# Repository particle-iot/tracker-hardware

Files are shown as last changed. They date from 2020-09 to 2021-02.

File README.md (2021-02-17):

# Tracker Hardware Resources

*Hardware repository for the Tracker SoM evaluation board and carrier board (Tracker One)*

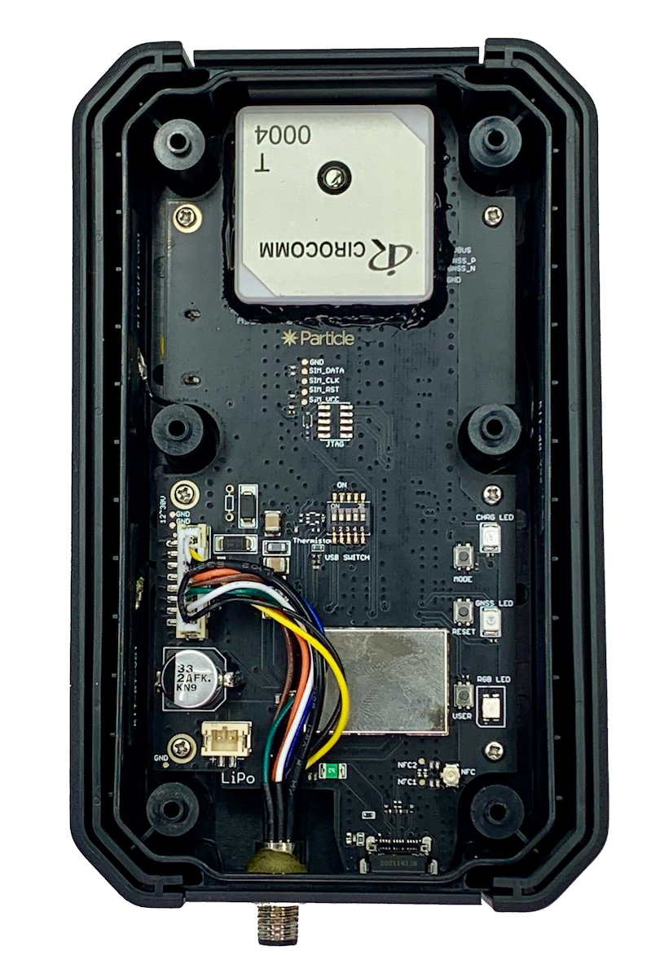
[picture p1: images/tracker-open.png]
Tracker One


Datasheets:

- [Tracker SoM](https://docs.particle.io/datasheets/asset-tracking/tracker-som-datasheet/)
- [Tracker SoM Evaluation Board](https://docs.particle.io/datasheets/asset-tracking/tracker-som-eval-board/)
- [Tracker One](https://docs.particle.io/datasheets/asset-tracking/tracker-one/)

In this repository you can find the following directories:

- eagle-eval: The Tracker SoM evaluation board
- eagle-carrier: The Tracker carrier board (the board in the Tracker One)

Within the Eagle directories are the standard Eagle files:

- *.sch Schematic file
- *.sch.pdf PDF version of the schematic (handy if you don't have Eagle CAD)
- *.brd Board Layout file
- *.lbr Library containing all of the components in the sch/brd files
- *.rar or *.zip Gerber files
- *.cam CAM file used to produce the Gerber file

The boards are identical for both Tracker SoM versions (T402 and T523).

Other useful resources include:

- [Creating your first Tracker SoM board tutorial](https://docs.particle.io/tutorials/asset-tracking/tracker-som-first-board/).

## Version History

### Tracker One (Carrier Board) v1.1 (2020-08-18)

1. Added TS3A5018 analog switch for isolate M8 IO pins.
2. Recalculated impedance, modified RF 50 ohm and USB 90 ohm trace width.
3. Added CAN BUS 5V output bypass fuse F2.

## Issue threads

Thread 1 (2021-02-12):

Potentially Incorrect Part Number

dan-os, 2021-02-12:
Hi there,

I noticed that LED3 (the RGB Particle status LED) from the "eagle-carrier" schematic has the part reference "LTST-T680UGWT" - I believe this is incorrect since this refers to a 2-pin green LED. I believe the intended part is the "150141M173100" by WURTH ELEKTRONIK.

Thanks for all your work!

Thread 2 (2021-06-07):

Schematics is not searchable

jhnlmn, 2021-06-07:
AT SoM Carrier Board V1.1 schematic.pdf
contains only screen shots from the schematics, which are neither searchable nor copyable.
All other chip/module makers provide schematics in PDF, where I can:
- search for a part name, for a trace name, etc
- copy part name to a browser to search for datasheet
but your schematics us close to be useless. I tried to use OCR on it, but it generates too many errors.
Please, provide real schematics for the Tracker

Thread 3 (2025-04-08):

Getting the Firmware Off of a Tracker One

redchairlabs, 2025-04-08:
I have been asked by a client to troubleshoot a Tracker One that is installed on a piece of equipment they own. The TO is receiving information via a CAN bus conenction but only a fraction of the data appears to be relayed out via the TO. Is there any way that I can pull the firmware off of the TO and verify that the CAN bus data file is configured correctly?

I have not worked with the Particle devices before and I am a bit unsure of how to configure the CAN bus connection in them.

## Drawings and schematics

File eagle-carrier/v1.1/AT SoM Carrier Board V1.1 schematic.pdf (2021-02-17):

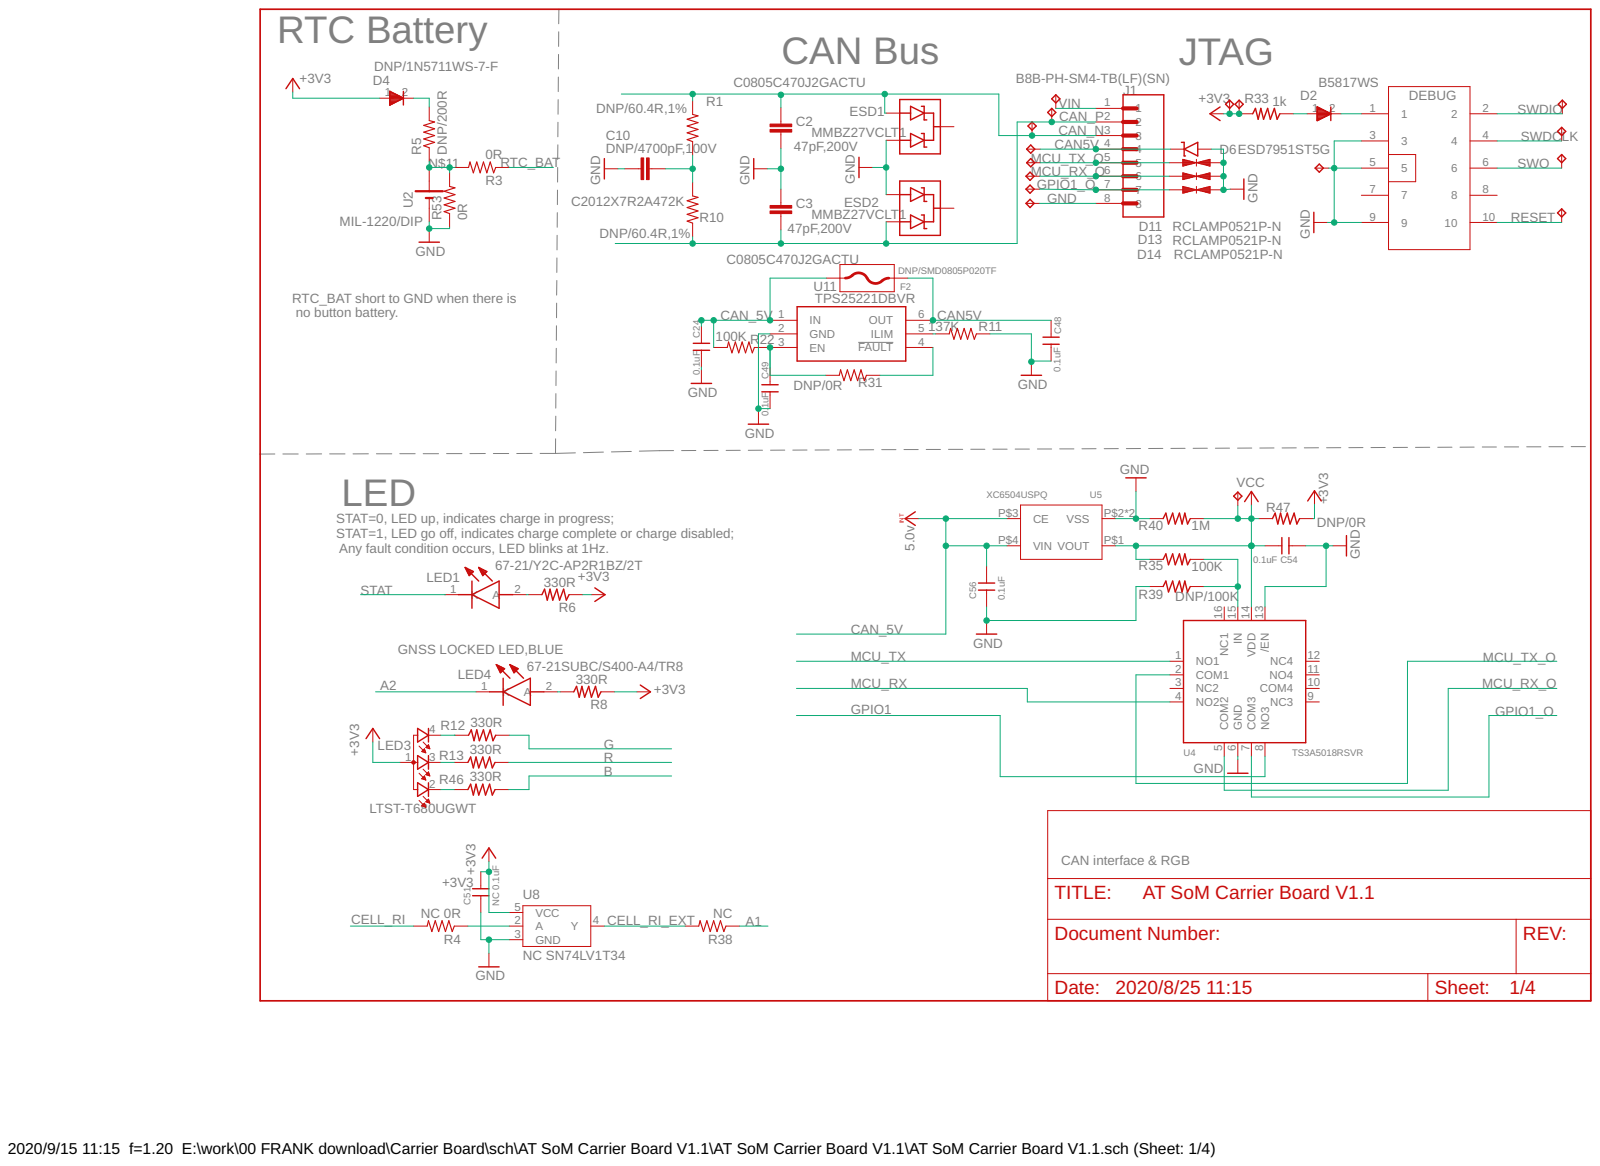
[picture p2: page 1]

RTC_BAT short to GND when there is
no button battery.

STAT=0, LED up, indicates charge in progress;
STAT=1, LED go off, indicates charge complete or charge disabled;
Any fault condition occurs, LED blinks at 1Hz. GNSS LOCKED LED,BLUE

AT SoM Carrier Board V1.1

Document Number: | REV:

Date: 2020/8/25 11:15 | Sheet: 1/4

2020/9/15 11:15 f=1.20 E:\work\00 FRANK download\Carrier Board\sch\AT SoM Carrier Board V1.1\AT SoM Carrier Board V1.1\AT SoM Carrier Board V1.1.sch (Sheet: 1/4)

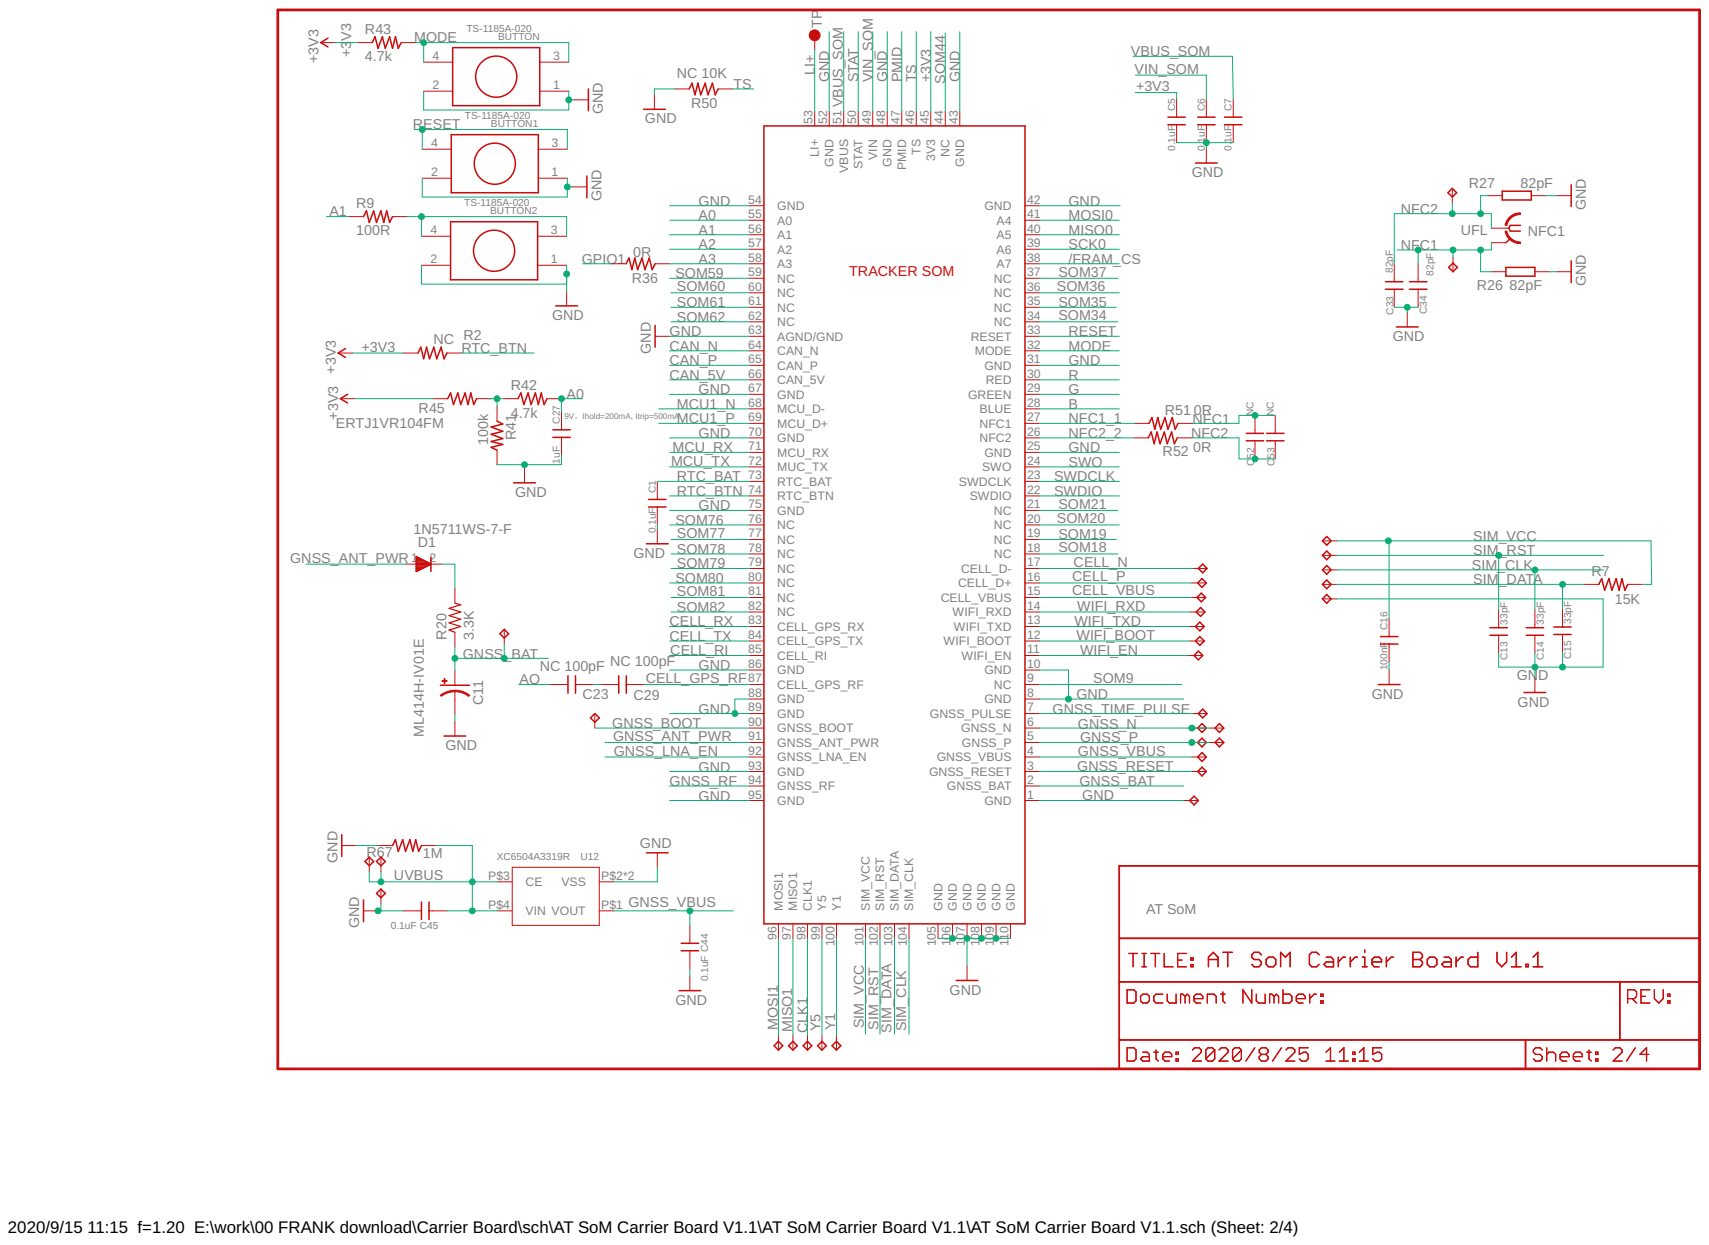
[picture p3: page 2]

2020/9/15 11:15 f=1.20 E:\work\00 FRANK download\Carrier Board\sch\AT SoM Carrier Board V1.1\AT SoM Carrier Board V1.1\AT SoM Carrier Board V1.1.sch (Sheet: 2/4)

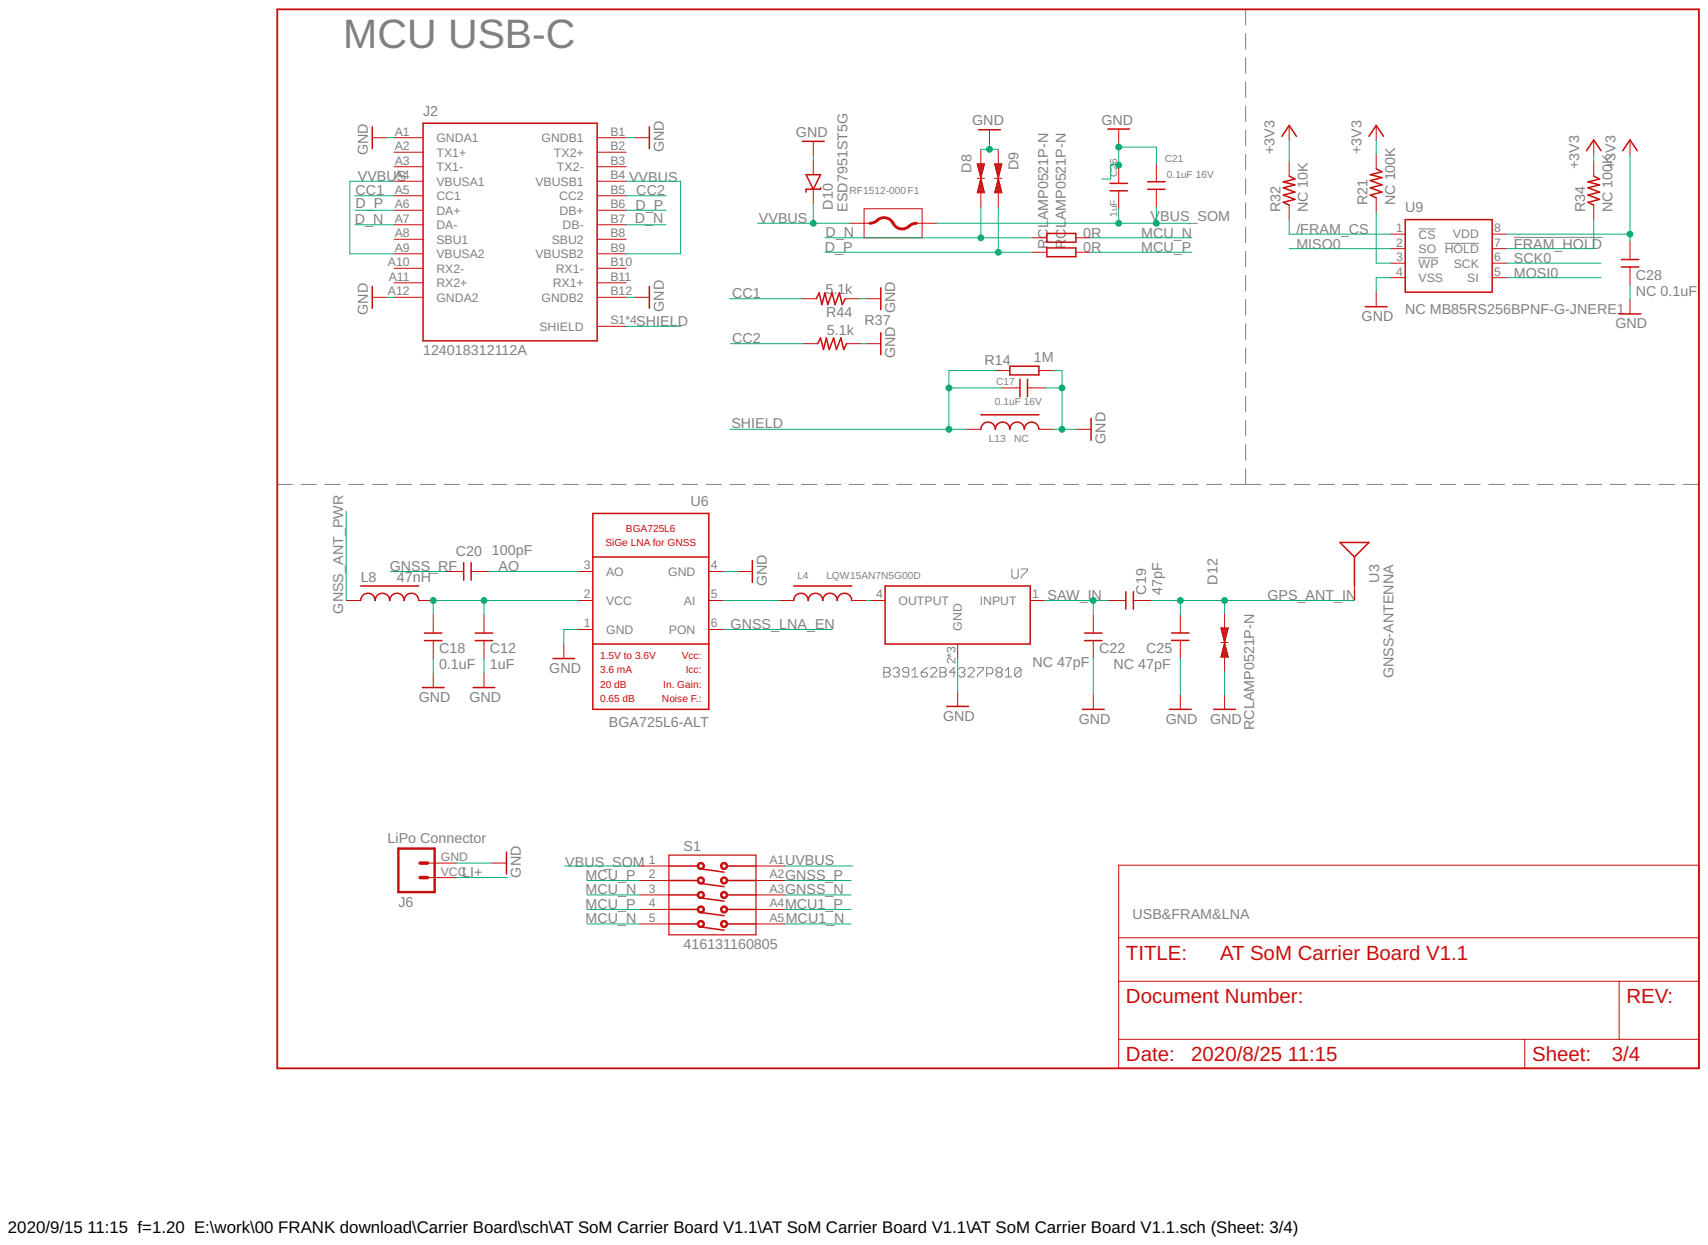
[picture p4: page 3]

BGA725L6 SiGe LNA for GNSS

AT SoM Carrier Board V1.1

Document Number: | REV:

Date: 2020/8/25 11:15 | Sheet: 3/4

2020/9/15 11:15 f=1.20 E:\work\00 FRANK download\Carrier Board\sch\AT SoM Carrier Board V1.1\AT SoM Carrier Board V1.1\AT SoM Carrier Board V1.1.sch (Sheet: 3/4)

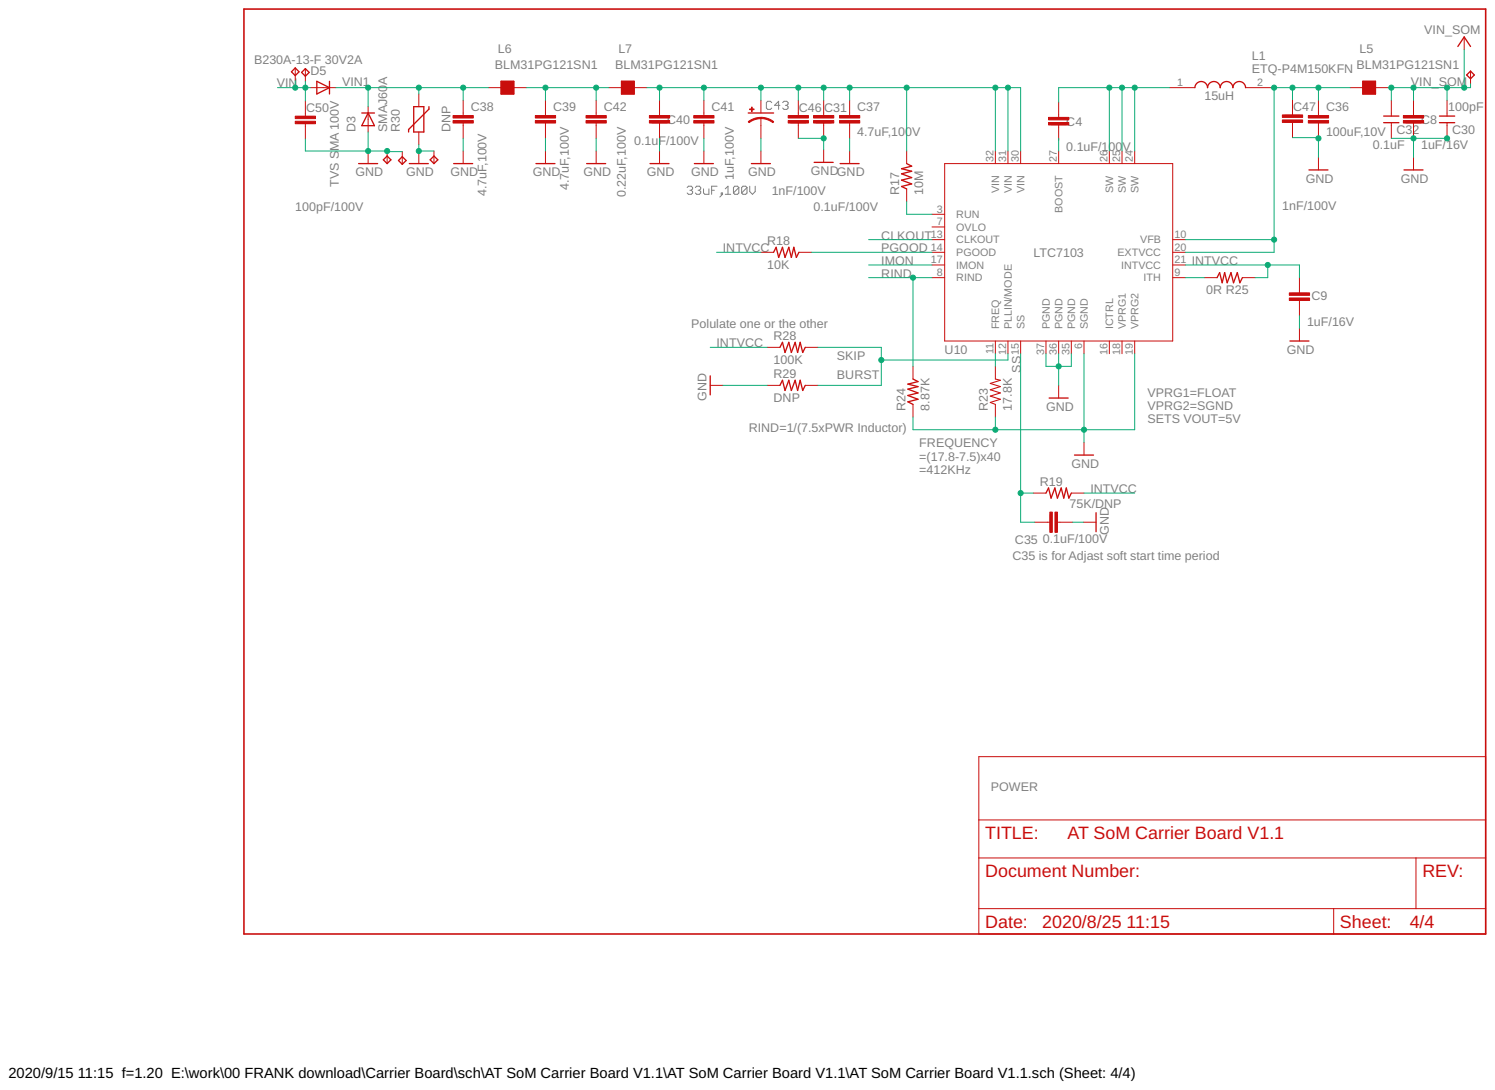
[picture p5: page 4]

VIN_SOM

Polulate one or the other
INTVCC

C35 is for Adjast soft start time period

AT SoM Carrier Board V1.1

Document Number: | REV:

Date: 2020/8/25 11:15 | Sheet: 4/4

2020/9/15 11:15 f=1.20 E:\work\00 FRANK download\Carrier Board\sch\AT SoM Carrier Board V1.1\AT SoM Carrier Board V1.1\AT SoM Carrier Board V1.1.sch (Sheet: 4/4)

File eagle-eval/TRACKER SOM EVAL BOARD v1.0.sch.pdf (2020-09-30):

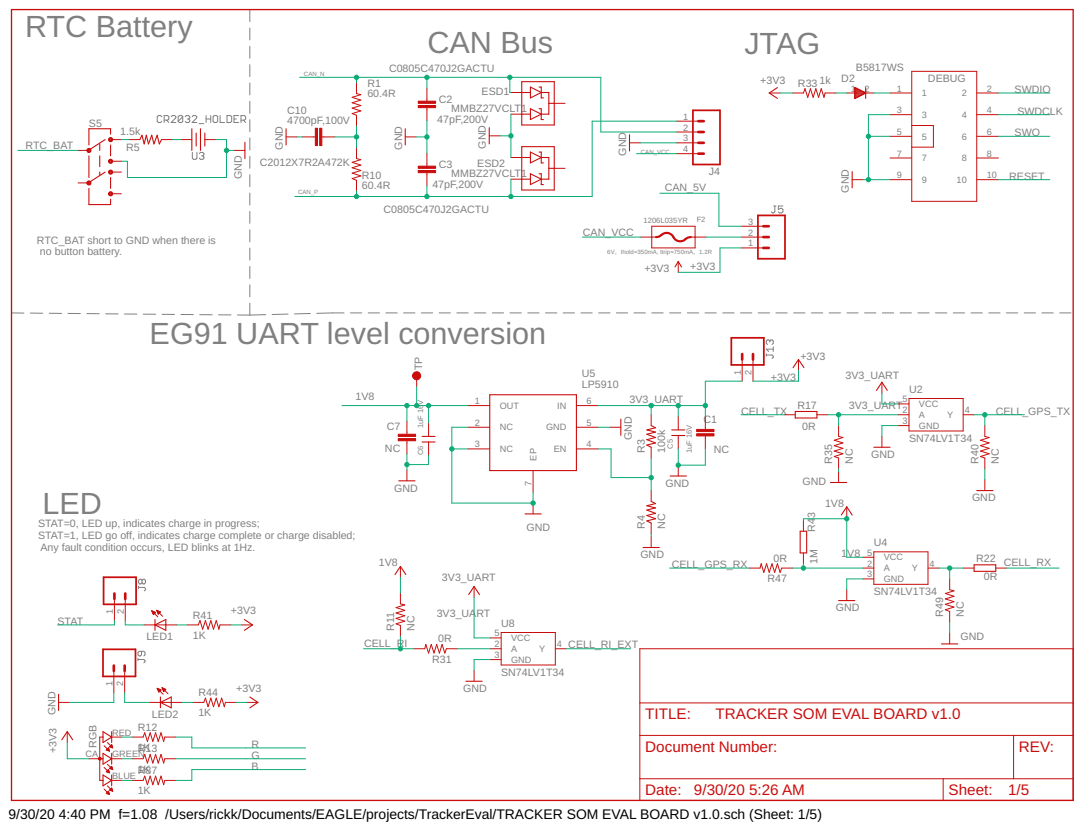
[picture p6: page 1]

RTC Battery | CAN Bus JTAG

RTC_BAT short to GND when there is no button battery.

STAT=0, LED up, indicates charge in progress;
STAT=1, LED go off, indicates charge complete or charge disabled;
Any fault condition occurs, LED blinks at 1Hz.

TRACKER SOM EVAL BOARD v1.0

Document Number: | REV:

Date: 9/30/20 5:26 AM | Sheet: 1/5

9/30/20 4:40 PM f=1.08 /Users/rickk/Documents/EAGLE/projects/TrackerEval/TRACKER SOM EVAL BOARD v1.0.sch (Sheet: 1/5)

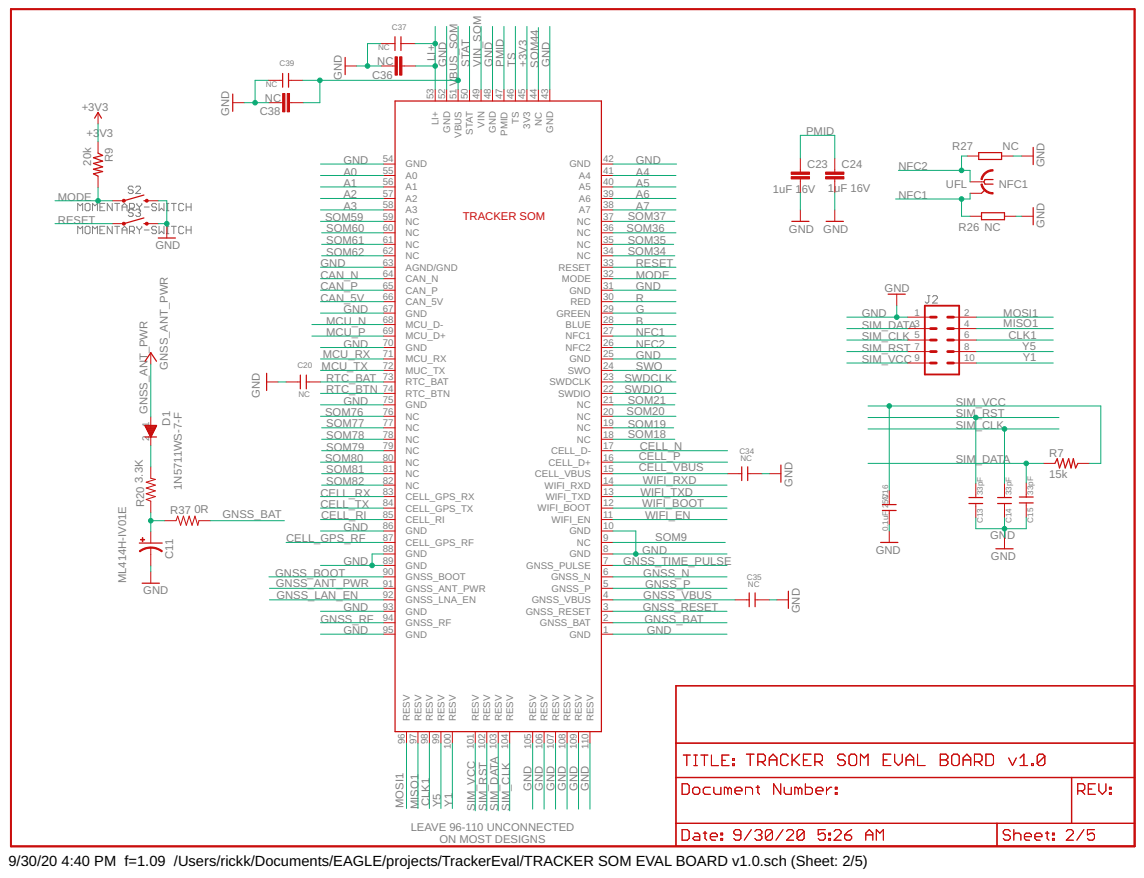
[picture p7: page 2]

9/30/20 4:40 PM f=1.09 /Users/rickk/Documents/EAGLE/projects/TrackerEval/TRACKER SOM EVAL BOARD v1.0.sch (Sheet: 2/5)

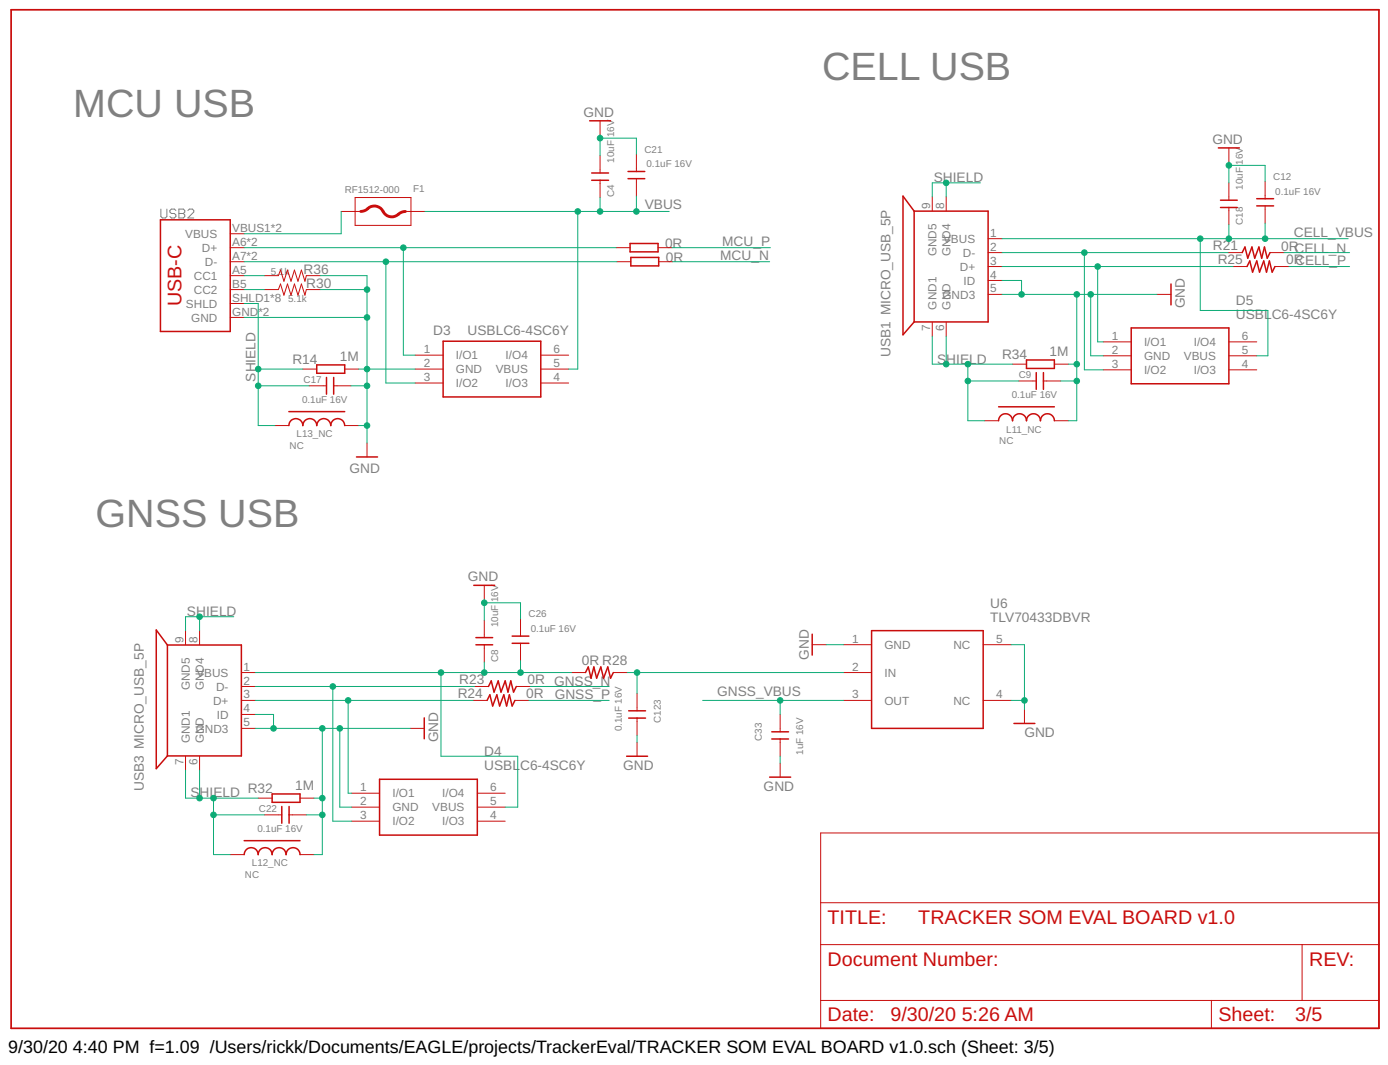
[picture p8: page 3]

3 | R24

TRACKER SOM EVAL BOARD v1.0

9/30/20 4:40 PM f=1.09 /Users/rickk/Documents/EAGLE/projects/TrackerEval/TRACKER SOM EVAL BOARD v1.0.sch (Sheet: 3/5)

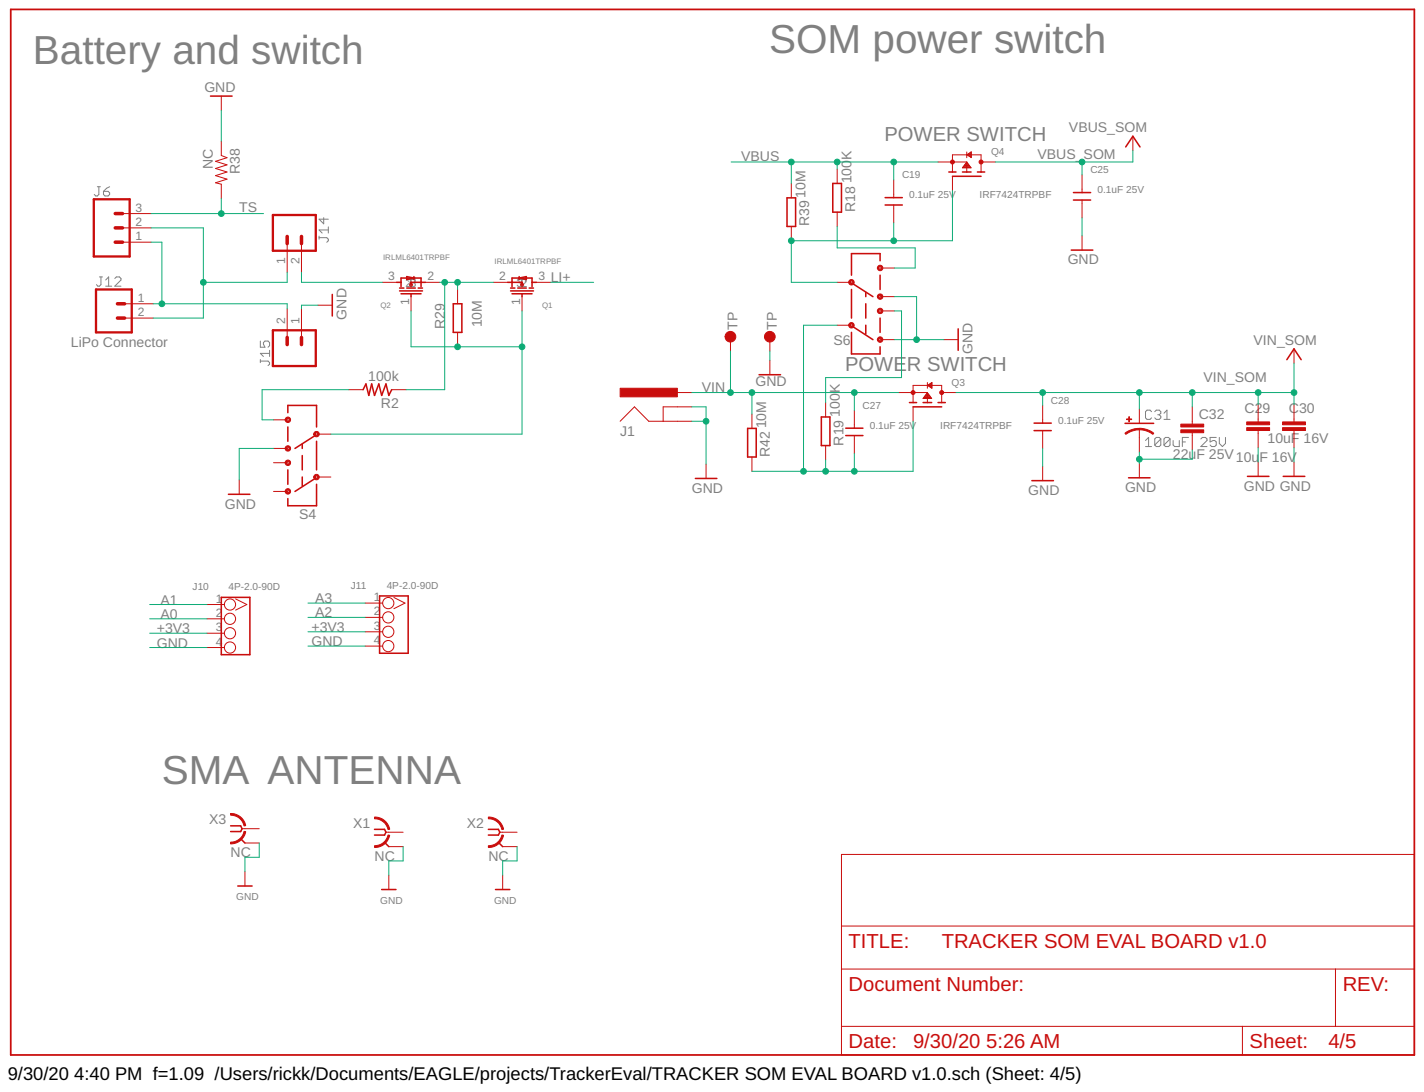
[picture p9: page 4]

TRACKER SOM EVAL BOARD v1.0

9/30/20 4:40 PM f=1.09 /Users/rickk/Documents/EAGLE/projects/TrackerEval/TRACKER SOM EVAL BOARD v1.0.sch (Sheet: 4/5)

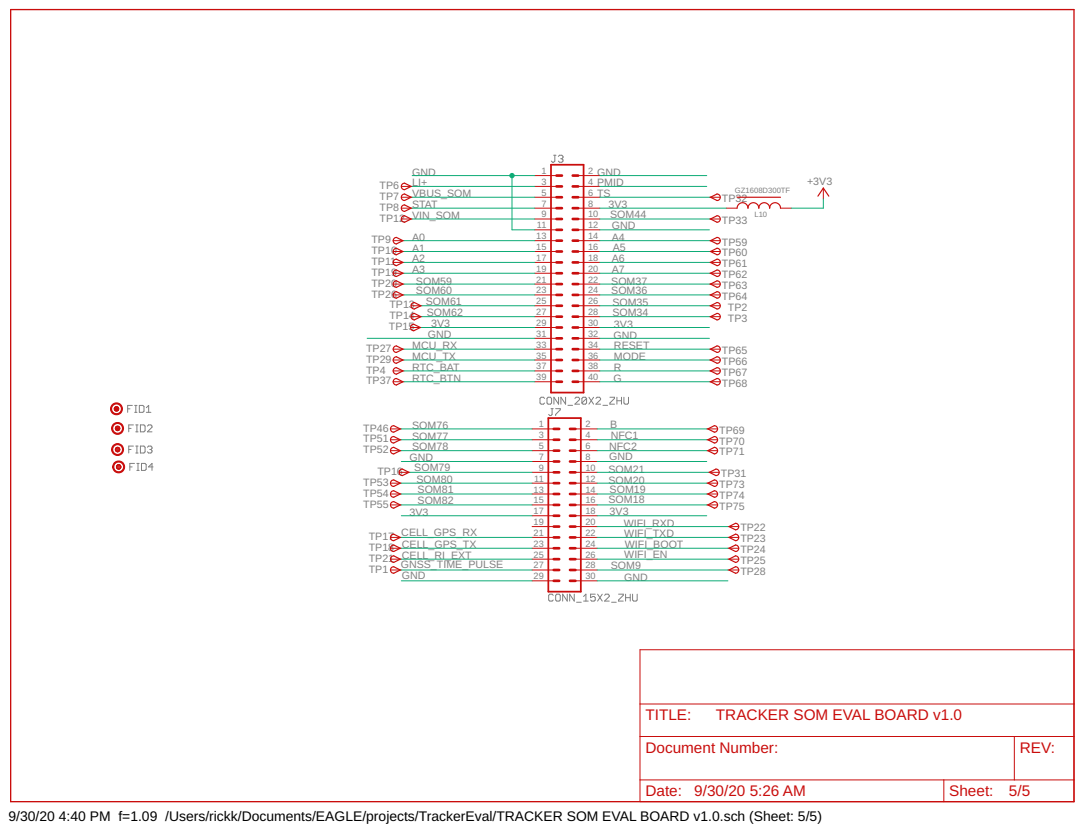
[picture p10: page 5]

TRACKER SOM EVAL BOARD v1.0

9/30/20 4:40 PM f=1.09 /Users/rickk/Documents/EAGLE/projects/TrackerEval/TRACKER SOM EVAL BOARD v1.0.sch (Sheet: 5/5)

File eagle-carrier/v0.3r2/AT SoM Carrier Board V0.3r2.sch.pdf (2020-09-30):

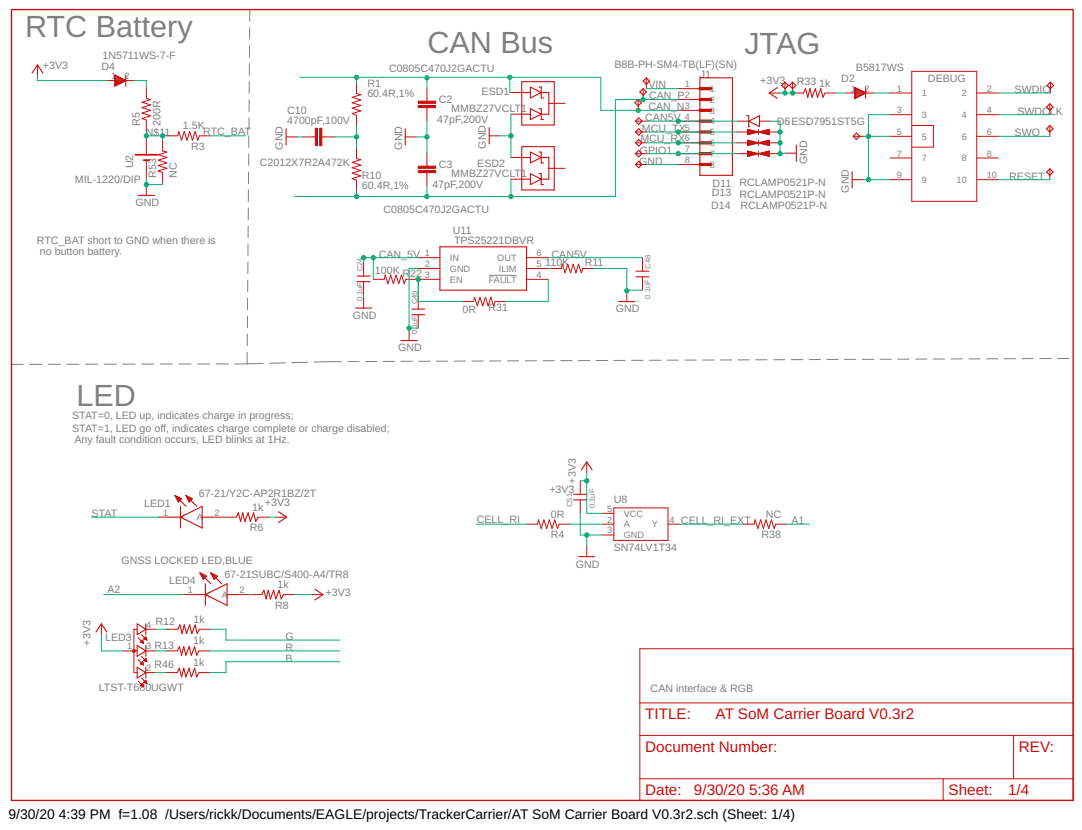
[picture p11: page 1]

RTC_BAT short to GND when there is no button battery.

STAT=0, LED up, indicates charge in progress;
STAT=1, LED go off, indicates charge complete or charge disabled;
Any fault condition occurs, LED blinks at 1Hz.

GNSS LOCKED LED,BLUE

AT SoM Carrier Board V0.3r2

Document Number: | REV:

Date: 9/30/20 5:36 AM | Sheet: 1/4

9/30/20 4:39 PM f=1.08 /Users/rickk/Documents/EAGLE/projects/TrackerCarrier/AT SoM Carrier Board V0.3r2.sch (Sheet: 1/4)

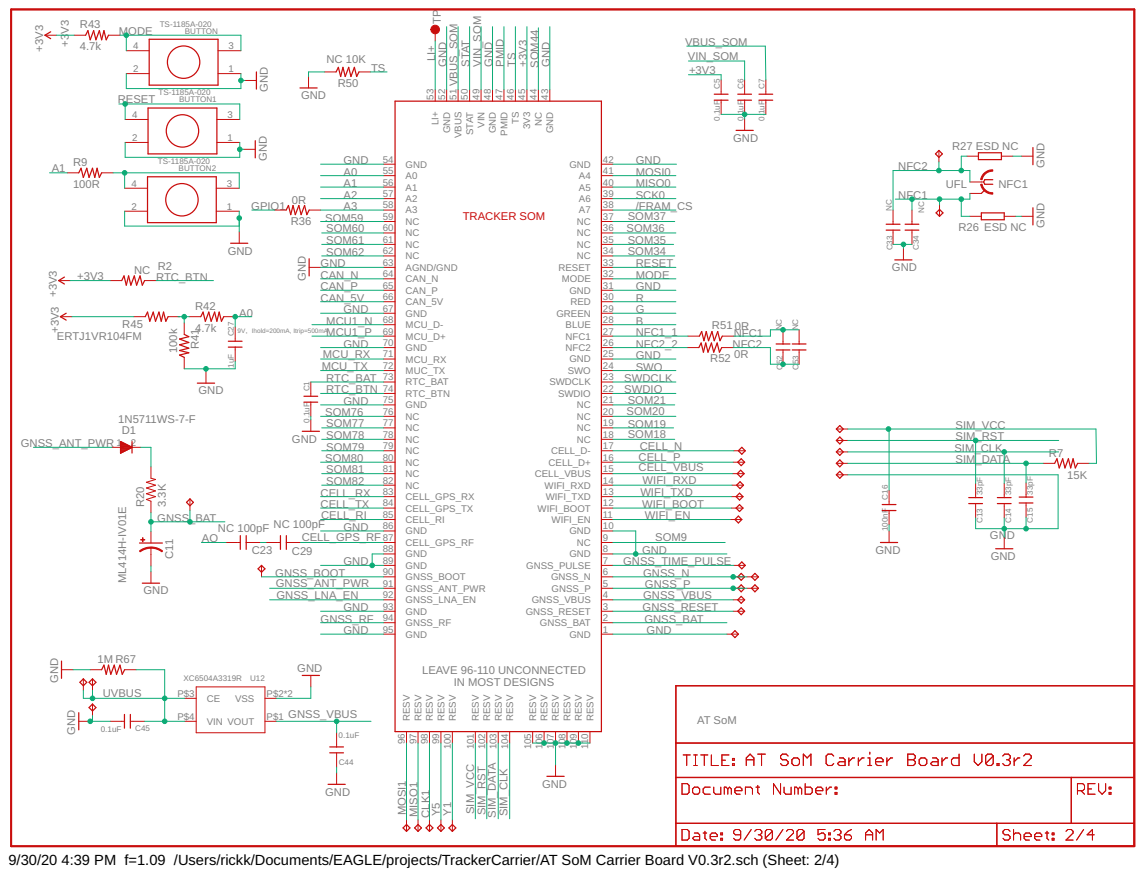
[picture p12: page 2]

9/30/20 4:39 PM f=1.09 /Users/rickk/Documents/EAGLE/projects/TrackerCarrier/AT SoM Carrier Board V0.3r2.sch (Sheet: 2/4)

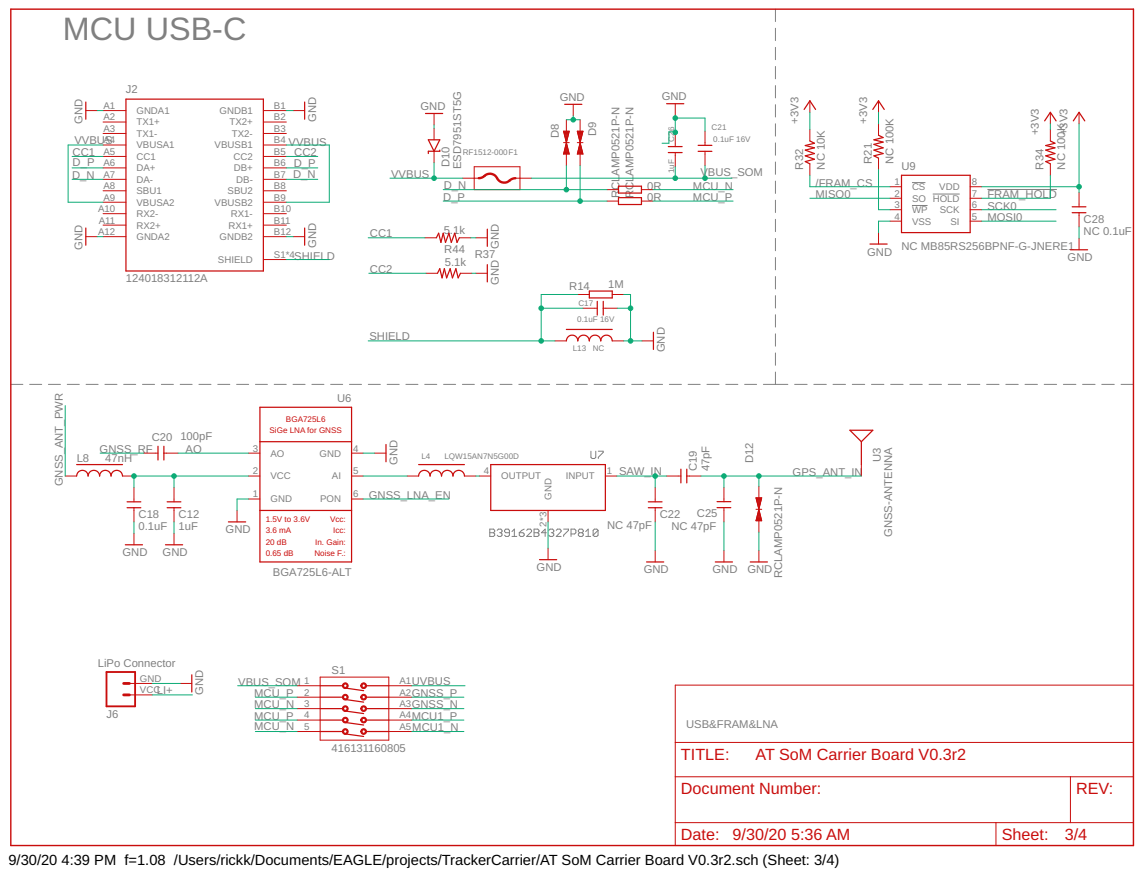
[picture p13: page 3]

BGA725L6 SiGe LNA for GNSS

AT SoM Carrier Board V0.3r2

9/30/20 4:39 PM f=1.08 /Users/rickk/Documents/EAGLE/projects/TrackerCarrier/AT SoM Carrier Board V0.3r2.sch (Sheet: 3/4)


Polulate one or the other SKIP
INTVCC

C35 is for Adjast soft start time period

AT SoM Carrier Board V0.3r2

9/30/20 4:39 PM f=1.09 /Users/rickk/Documents/EAGLE/projects/TrackerCarrier/AT SoM Carrier Board V0.3r2.sch (Sheet: 4/4)

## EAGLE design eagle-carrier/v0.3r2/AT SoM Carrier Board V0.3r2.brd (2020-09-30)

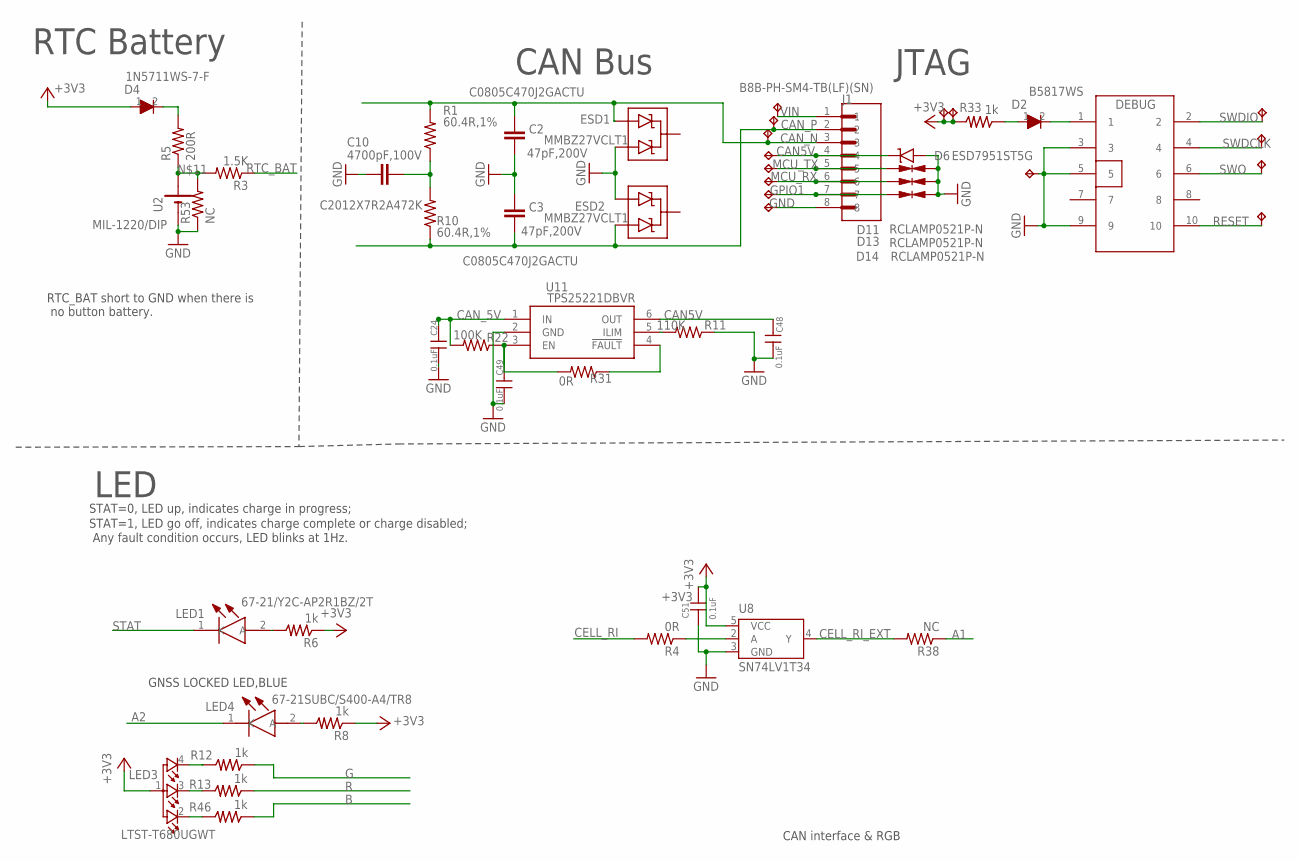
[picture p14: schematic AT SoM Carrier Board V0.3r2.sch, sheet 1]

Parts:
C2, C3: 47pF,200V; C0805; PART_NUMBER C0805C470J2GACTU
C10: 4700pF,100V; C0805; PART_NUMBER C2012X7R2A472K
C24, C48, C49, C51: 0.1uF; C-0402
D2: B5817WS; SOD-323
D4: 1N5711WS-7-F; SOD-323
D6: ESD7951ST5G; 0402-TVS-UNIDIR
D11, D13, D14: RCLAMP0521P-N; C0402
DEBUG: CON5X2; CON5X2_1.27
ESD1, ESD2: MMBZ27VCLT1; SOT23-3
J1: B8B-PH-SM4-TB(LF)(SN); JST_B8B-PH-SM4-TB(LF)(SN)
LED1: 67-21/Y2C-AP2R1BZ/2T; LEDM3528X210N
LED3: LTST-T680UGWT; 150141M173100
LED4: 67-21SUBC/S400-A4/TR8; LEDM3528X210N
R1, R10: 60.4R,1%; R1206
R3: 1.5K; R0402_B
R4, R31: 0R; R0402_B
R5: 200R; R0402_B
R6, R8, R12, R13, R33, R46: 1k; R-0402S
R11: 110K; R0402_B
R22: 100K; R0402_B
R38, R53: NC; R0402_B
TP11, TP12, TP13, TP15, TP16, TP21, TP22, TP43, TP46, TP47, TP48, TP49, TP50, TP51, TP52: TPTP10R; TP10R
U2: MIL-1220/DIP; BAT_ML-1220/DIP
U8: SN74LV1T34; SC70-5
U11: TPS25221DBVR; SOT95P280X145-6N

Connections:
+3V3: C51.1, D4.1, LED3.1, R6.1, R8.1, R33.2, TP16.TP, TP21.TP, U8.5 (VCC); also elsewhere on the board
A1: R38.1; also elsewhere on the board
A2: LED4.1 (K); also elsewhere on the board
B: R46.1; also elsewhere on the board
CAN5V: C48.1, D6.1, J1.4, TP48.TP, U11.6 (OUT)
CAN_5V: C24.1, R22.2, U11.1 (IN); also elsewhere on the board
CAN_N: C2.1, ESD1.2 (A2), J1.3, R1.2, TP47.TP; also elsewhere on the board
CAN_P: C3.2, ESD2.1 (A1), J1.2, R10.1, TP46.TP; also elsewhere on the board
CELL_RI: R4.2; also elsewhere on the board
CELL_RI_EXT: R38.2, U8.4 (Y)
G: R12.1; also elsewhere on the board
GND: C2.2, C3.1, C10.1, C24.2, C48.2, C49.2, C51.2, D6.2, D11.2, D13.2, D14.2, DEBUG.3, DEBUG.5, DEBUG.9, ESD1.1 (A1), ESD2.2 (A2), J1.8, R11.1, R53.1, TP22.TP, TP52.TP, U2.1 (N), U8.3 (GND), U11.2 (GND); also elsewhere on the board
GPIO1: D14.1, J1.7, TP51.TP; also elsewhere on the board
MCU_RX: D13.1, J1.6, TP50.TP; also elsewhere on the board
MCU_TX: D11.1, J1.5, TP49.TP; also elsewhere on the board
unnamed: LED1.2 (A), R6.2
unnamed: LED4.2 (A), R8.2
unnamed: R4.1, U8.2 (A)
unnamed: D2.2, DEBUG.1
unnamed: C10.2, R1.1, R10.2
unnamed: R11.2, U11.5 (ILIM)
unnamed: R3.2, R5.1, R53.2, U2.2
unnamed: C49.1, R22.1, R31.2, U11.3 (EN)
unnamed: LED3.4, R12.2
unnamed: R31.1, U11.4 (!FAULT)
unnamed: D4.2, R5.2
unnamed: LED3.2, R46.2
unnamed: LED3.3, R13.2
unnamed: D2.1, R33.1
R: R13.1; also elsewhere on the board
RESET: DEBUG.10, TP11.TP; also elsewhere on the board
RTC_BAT: R3.1; also elsewhere on the board
STAT: LED1.1 (K); also elsewhere on the board
SWDCLK: DEBUG.4, TP13.TP; also elsewhere on the board
SWDIO: DEBUG.2, TP15.TP; also elsewhere on the board
SWO: DEBUG.6, TP12.TP; also elsewhere on the board
VIN: J1.1, TP43.TP; also elsewhere on the board

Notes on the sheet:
CAN Bus
LED
JTAG
RTC Battery
RTC_BAT short to GND when there is no button battery.
STAT=0, LED up, indicates charge in progress;
STAT=1, LED go off, indicates charge complete or charge disabled;
Any fault condition occurs, LED blinks at 1Hz.
GNSS LOCKED LED,BLUE
CAN interface & RGB

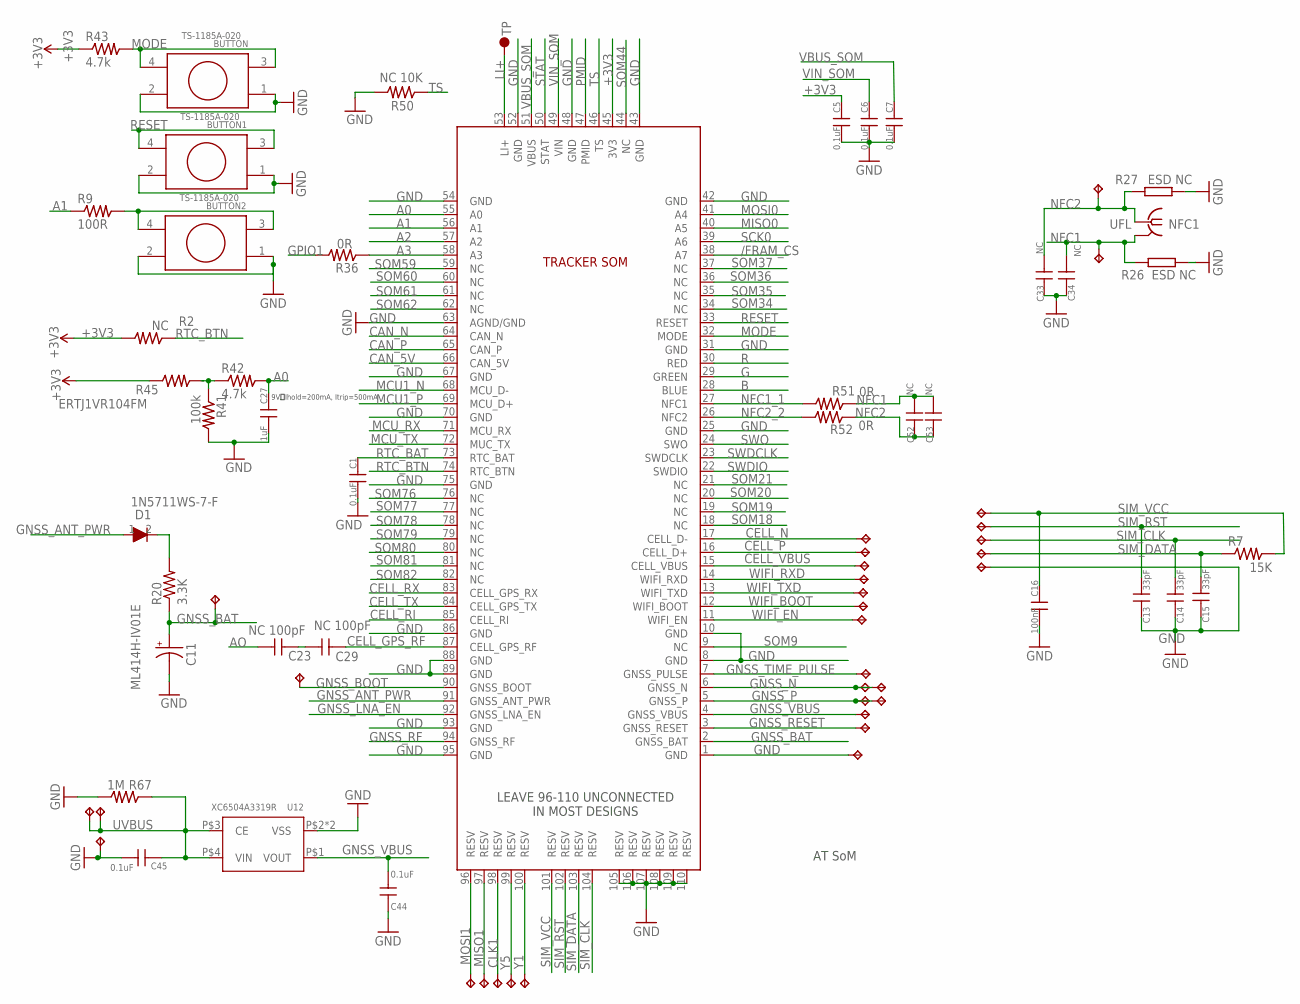
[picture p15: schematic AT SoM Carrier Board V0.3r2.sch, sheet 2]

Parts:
BUTTON, BUTTON1, BUTTON2: TS-1185A-020
C1, C5, C6, C7: 0.1uF; C-0402
C11: ML414H-IV01E; ML414H
C13, C14, C15: 33pF; C-0402
C16: 100nF; C-0402
C23, C29: NC 100pF; C0402_P
C27: 1uF; C-0402
C33, C34, C52, C53: NC; C-0402
C44, C45: 0.1uF; C0201-S
D1: 1N5711WS-7-F; SOD-323
NFC1: UFL; IPEX-20279-001E
R2: NC; R-0402S
R7: 15K; R-0402S
R9: 100R; R-0402S
R20: 3.3K; R0603_P
R26, R27: ESD NC; R-0402S
R36, R51, R52: 0R; R-0402S
R41: 100k; R-0402S
R42, R43: 4.7k; R-0402S
R45: ERTJ1VR104FM; R0603
R50: NC 10K; R-0402S
R67: 1M; R0201-S
TP1, TP2, TP3, TP4, TP5, TP6, TP7, TP8, TP9, TP14, TP17, TP18, TP19, TP20, TP27, TP28, TP29, TP30, TP31, TP32, TP33, TP34, TP35, TP36, TP37, TP38, TP39, TP40, TP41, TP42: TPTP10R; TP10R
U1: TRACKER-SOM-3A
U12: XC6504A3319R; USPQ-4B04
U$1: TP2; TP70_BOT
U$9, U$10: TPTP10R; TP10R

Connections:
+3V3: C5.1, R2.2, R43.1, R45.1, U1.45 (3V3); also elsewhere on the board
/FRAM_CS: U1.38 (A7); also elsewhere on the board
A0: C27.1, R42.2, U1.55 (A0)
A1: R9.1, U1.56 (A1); also elsewhere on the board
A2: U1.57 (A2); also elsewhere on the board
A3: R36.1, U1.58 (A3)
AO: C23.1; also elsewhere on the board
B: U1.28 (BLUE); also elsewhere on the board
CAN_5V: U1.66 (CAN_5V); also elsewhere on the board
CAN_N: U1.64 (CAN_N); also elsewhere on the board
CAN_P: U1.65 (CAN_P); also elsewhere on the board
CELL_GPS_RF: C29.2, U1.87 (CELL_GPS_RF)
CELL_N: TP38.TP, U1.17 (CELL_D-)
CELL_P: TP36.TP, U1.16 (CELL_D+)
CELL_RI: U1.85 (CELL_RI); also elsewhere on the board
CELL_RX: U1.83 (CELL_GPS_RX)
CELL_TX: U1.84 (CELL_GPS_TX)
CELL_VBUS: TP35.TP, U1.15 (CELL_VBUS)
CLK1: TP40.TP, U1.98 (RESV)
G: U1.29 (GREEN); also elsewhere on the board
GND: BUTTON.1, BUTTON.2, BUTTON1.1, BUTTON1.2, BUTTON2.1, BUTTON2.2, C1.2, C5.2, C6.2, C7.2, C11.-, C13.1, C14.1, C15.1, C16.2, C27.2, C33.1, C34.1, C44.1, C45.2, R26.2, R27.1, R41.2, R50.2, R67.2, TP18.TP, TP20.TP, TP32.TP, U1.1 (GND), U1.8 (GND), U1.10 (GND), U1.25 (GND), U1.31 (GND), U1.42 (GND), U1.43 (GND), U1.48 (GND), U1.52 (GND), U1.54 (GND), U1.63 (AGND/GND), U1.67 (GND), U1.70 (GND), U1.75 (GND), U1.86 (GND), U1.88 (GND), U1.89 (GND), U1.93 (GND), U1.95 (GND), U1.105 (RESV), U1.106 (RESV), U1.107 (RESV), U1.108 (RESV), U1.109 (RESV), U1.110 (RESV), U12.P$2 (VSS), U12.P$5 (VSS); also elsewhere on the board
GNSS_ANT_PWR: D1.1, U1.91 (GNSS_ANT_PWR); also elsewhere on the board
GNSS_BAT: C11.+, R20.1, TP9.TP, U1.2 (GNSS_BAT)
GNSS_BOOT: TP6.TP, U1.90 (GNSS_BOOT)
GNSS_LNA_EN: U1.92 (GNSS_LNA_EN); also elsewhere on the board
GNSS_N: TP14.TP, TP34.TP, U1.6 (GNSS_N); also elsewhere on the board
GNSS_P: TP5.TP, TP19.TP, U1.5 (GNSS_P); also elsewhere on the board
GNSS_RESET: TP8.TP, U1.3 (GNSS_RESET)
GNSS_RF: U1.94 (GNSS_RF); also elsewhere on the board
GNSS_TIME_PULSE: TP7.TP, U1.7 (GNSS_PULSE)
GNSS_VBUS: C44.2, TP30.TP, U1.4 (GNSS_VBUS), U12.P$1 (VOUT)
GPIO1: R36.2; also elsewhere on the board
LI+: U1.53 (LI+), U$1.P$1; also elsewhere on the board
MCU1_N: U1.68 (MCU_D-); also elsewhere on the board
MCU1_P: U1.69 (MCU_D+); also elsewhere on the board
MCU_RX: U1.71 (MCU_RX); also elsewhere on the board
MCU_TX: U1.72 (MUC_TX); also elsewhere on the board
MISO0: U1.40 (A5); also elsewhere on the board
MISO1: TP39.TP, U1.97 (RESV)
MODE: BUTTON.3, BUTTON.4, R43.2, U1.32 (MODE)
MOSI0: U1.41 (A4); also elsewhere on the board
MOSI1: TP37.TP, U1.96 (RESV)
unnamed: R41.1, R42.1, R45.2
unnamed: D1.2, R20.2
unnamed: C23.2, C29.1
unnamed: BUTTON2.3, BUTTON2.4, R9.2
NFC1: C34.2, C52.2, C53.2, NFC1.2@1 (GND), NFC1.2@2 (GND), R26.1, R51.1, U$10.TP
NFC1_1: R51.2, U1.27 (NFC1)
NFC2: C33.2, C52.1, C53.1, NFC1.1, R27.2, R52.1, U$9.TP
NFC2_2: R52.2, U1.26 (NFC2)
PMID: U1.47 (PMID)
R: U1.30 (RED); also elsewhere on the board
RESET: BUTTON1.3, BUTTON1.4, U1.33 (RESET); also elsewhere on the board
RTC_BAT: C1.1, U1.73 (RTC_BAT); also elsewhere on the board
RTC_BTN: R2.1, U1.74 (RTC_BTN)
SCK0: U1.39 (A6); also elsewhere on the board
SIM_CLK: C14.2, TP29.TP, U1.104 (RESV)
SIM_DATA: C15.2, R7.1, TP31.TP, U1.103 (RESV)
SIM_RST: C13.2, TP28.TP, U1.102 (RESV)
SIM_VCC: C16.1, R7.2, TP27.TP, U1.101 (RESV)
SOM9: U1.9 (NC)
SOM18: U1.18 (NC)
SOM19: U1.19 (NC)
SOM20: U1.20 (NC)
SOM21: U1.21 (NC)
SOM34: U1.34 (NC)
SOM35: U1.35 (NC)
SOM36: U1.36 (NC)
SOM37: U1.37 (NC)
SOM44: U1.44 (NC)
SOM59: U1.59 (NC)
SOM60: U1.60 (NC)
SOM61: U1.61 (NC)
SOM62: U1.62 (NC)
SOM76: U1.76 (NC)
SOM77: U1.77 (NC)
SOM78: U1.78 (NC)
SOM79: U1.79 (NC)
SOM80: U1.80 (NC)
SOM81: U1.81 (NC)
SOM82: U1.82 (NC)
STAT: U1.50 (STAT); also elsewhere on the board
SWDCLK: U1.23 (SWDCLK); also elsewhere on the board
SWDIO: U1.22 (SWDIO); also elsewhere on the board
SWO: U1.24 (SWO); also elsewhere on the board
TS: R50.1, U1.46 (TS)
UVBUS: C45.1, R67.1, TP17.TP, TP33.TP, U12.P$3 (CE), U12.P$4 (VIN); also elsewhere on the board
VBUS_SOM: C7.1, U1.51 (VBUS); also elsewhere on the board
VIN_SOM: C6.1, U1.49 (VIN); also elsewhere on the board
WIFI_BOOT: TP3.TP, U1.12 (WIFI_BOOT)
WIFI_EN: TP4.TP, U1.11 (WIFI_EN)
WIFI_RXD: TP1.TP, U1.14 (WIFI_RXD)
WIFI_TXD: TP2.TP, U1.13 (WIFI_TXD)
Y1: TP42.TP, U1.100 (RESV)
Y5: TP41.TP, U1.99 (RESV)

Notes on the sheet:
AT SoM
9V，Ihold=200mA, Itrip=500mA
LEAVE 96-110 UNCONNECTED IN MOST DESIGNS

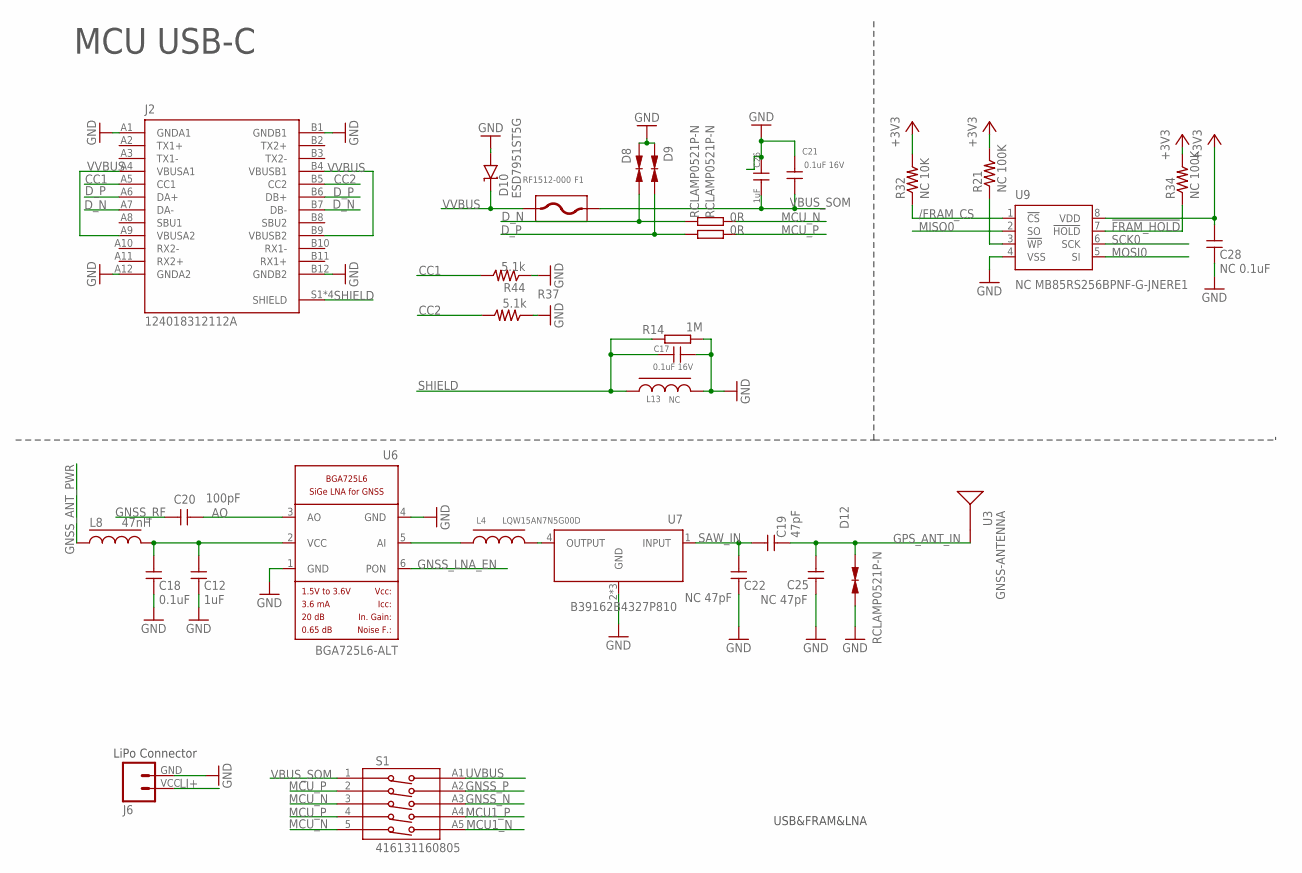
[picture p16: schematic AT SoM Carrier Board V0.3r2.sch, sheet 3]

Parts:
C12: 1uF; C0402_P
C17: 0.1uF 16V; PARTICLE-SZ_C-0402
C18: 0.1uF; C0402_P
C19: 47pF; C0402_P
C20: 100pF; C0402_P
C21: 0.1uF 16V; C-0402
C22, C25: NC 47pF; C0402_P
C26: 1uF; C-0402
C28: NC 0.1uF; C0402_P
D8, D9, D12: RCLAMP0521P-N; C0402
D10: ESD7951ST5G; 0402-TVS-UNIDIR
F1: RF1512-000; R1206
J2: 124018312112A; AMPHENOL_124018312112A
J6: M024UCON-15767; JST-2-SMD-VERT
L4: LQW15AN7N5G00D; R-0402S
L8: 47nH; R-0402S
L13: NC; R-0603A
R14: 1M; REDBEAR_R0603
R15, R16: 0R; R-0402S
R21, R34: NC 100K; R-0402S
R32: NC 10K; R-0402S
R37, R44: 5.1k; R-0402S
S1: 416131160805
U3: GNSS-ANTENNA; PA035AZ0004
U6: BGA725L6-ALT; LNA-TSLP-6-2-ALT
U7: B39162B4327P810; QCS5I
U9: NC MB85RS256BPNF-G-JNERE1; SO08

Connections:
!FRAM_HOLD: R34.1, U9.7 (!HOLD)
!FRAM_WP: R21.1, U9.3 (!WP)
+3V3: C28.1, R21.2, R32.2, R34.2, U9.8 (VDD); also elsewhere on the board
/FRAM_CS: R32.1, U9.1 (!CS); also elsewhere on the board
AO: C20.2, U6.3 (AO); also elsewhere on the board
CC1: J2.A5 (CC1), R44.2
CC2: J2.B5 (CC2), R37.2
D_N: D8.2, J2.A7 (DA-), J2.B7 (DB-), R15.1
D_P: D9.2, J2.A6 (DA+), J2.B6 (DB+), R16.1
GND: C12.2, C17.2, C18.2, C21.2, C22.2, C25.1, C26.1, C28.2, D8.1, D9.1, D10.2, D12.2, J2.A1 (GNDA1), J2.A12 (GNDA2), J2.B1 (GNDB1), J2.B12 (GNDB2), J6.GND (1), L13.2, R14.2, R37.1, R44.1, U6.1 (GND), U6.4 (GND), U7.2 (GND), U7.3 (GND), U7.5 (GND), U9.4 (VSS); also elsewhere on the board
GNSS_ANT_PWR: L8.1; also elsewhere on the board
GNSS_LNA_EN: U6.6 (PON); also elsewhere on the board
GNSS_N: S1.A3; also elsewhere on the board
GNSS_P: S1.A2; also elsewhere on the board
GNSS_RF: C20.1; also elsewhere on the board
GPS_ANT_IN: C19.2, C25.2, D12.1, U3.P$1
LI+: J6.VCC (2); also elsewhere on the board
MCU1_N: S1.A5; also elsewhere on the board
MCU1_P: S1.A4; also elsewhere on the board
MCU_N: R15.2, S1.3, S1.5
MCU_P: R16.2, S1.2, S1.4
MISO0: U9.2 (SO); also elsewhere on the board
MOSI0: U9.5 (SI); also elsewhere on the board
unnamed: L4.2, U7.4 (OUTPUT)
unnamed: L4.1, U6.5 (AI)
unnamed: C12.1, C18.1, L8.2, U6.2 (VCC)
SAW_IN: C19.1, C22.1, U7.1 (INPUT)
SCK0: U9.6 (SCK); also elsewhere on the board
SHIELD: C17.1, J2.S1 (SHIELD), J2.S2 (SHIELD), J2.S3 (SHIELD), J2.S4 (SHIELD), L13.1, R14.1
UVBUS: S1.A1; also elsewhere on the board
VBUS_SOM: C21.1, C26.2, F1.2, S1.1; also elsewhere on the board
VVBUS: D10.1, F1.1, J2.A4 (VBUSA1), J2.A9 (VBUSA2), J2.B4 (VBUSB1), J2.B9 (VBUSB2)

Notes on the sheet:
MCU USB-C
USB&FRAM&LNA
LiPo Connector

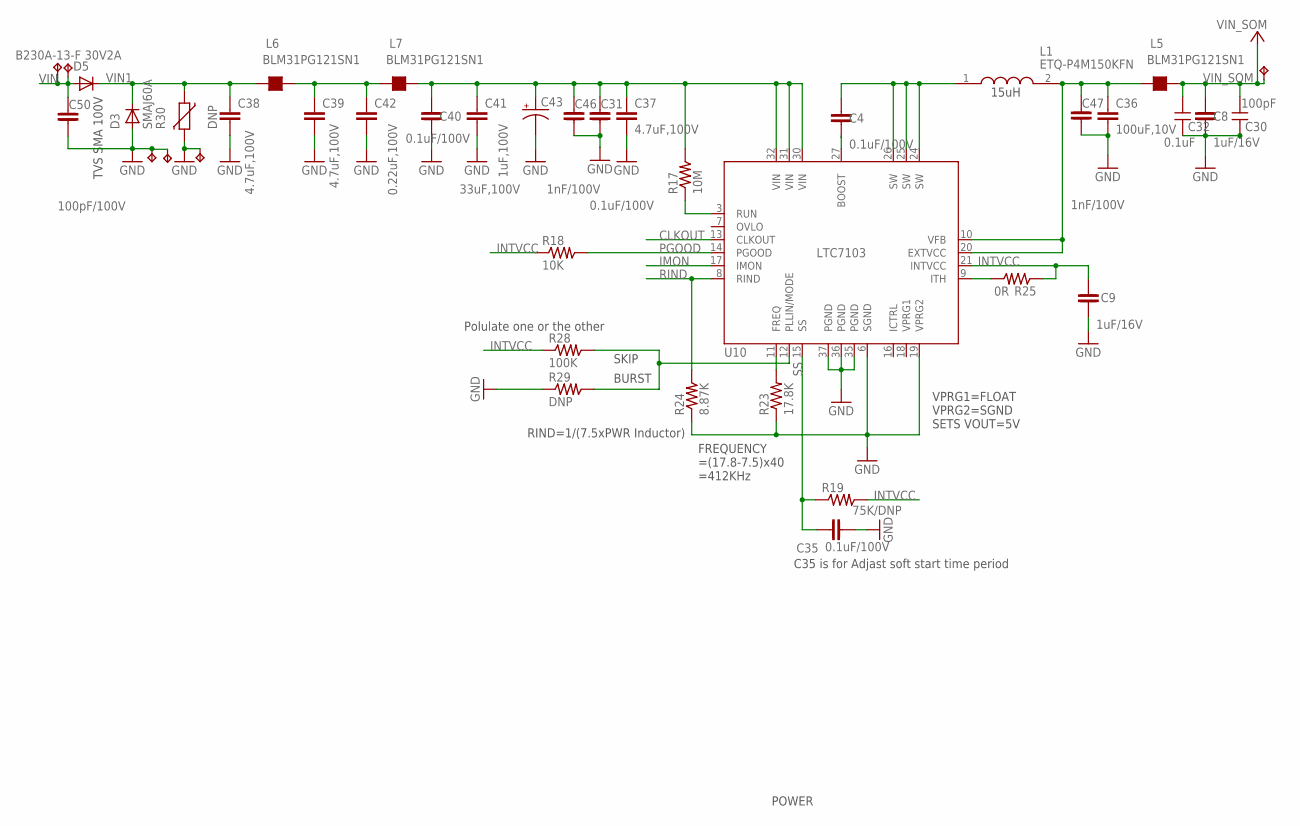
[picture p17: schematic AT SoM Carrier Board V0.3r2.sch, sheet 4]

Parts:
C4, C31, C35, C40: 0.1uF/100V; C-0603A
C8, C9: 1uF/16V; C-0402
C30: 100pF; C0402_P
C32: 0.1uF; C0402_P
C36: 100uF,10V; C1210
C37, C38, C39: 4.7uF,100V; C1210
C41: 1uF,100V; C0805
C42: 0.22uF,100V; C0805
C43: 33uF,100V; NIC_10X10.5_CAP
C46, C47: 1nF/100V; C-0603A
C50: 100pF/100V; C-0603A
D3: SMAJ60A; SMADIODE
D5: B230A-13-F 30V2A; SMADIODE
L1: ETQ-P4M150KFN; ETQP4M150KFN
L5, L6, L7: BLM31PG121SN1; L1206
R17: 10M; R-0402S
R18: 10K; R-0402S
R19: 75K/DNP; R-0402S
R23: 17.8K; R0603_P
R24: 8.87K; R-0402S
R25: 0R; R-0402S
R28: 100K; R-0402S
R29: DNP; R-0402S
R30: DNP; R-5
TP10, TP23, TP24, TP25, TP26, TP45: TPTP10R; TP10R
U10: LTC7103; UHE36(26)QFN

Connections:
CLKOUT: U10.13 (CLKOUT)
GND: C8.2, C9.2, C30.2, C31.2, C32.2, C35.2, C36.2, C37.2, C38.2, C39.2, C40.2, C41.2, C42.2, C43.-, C46.2, C47.2, C50.2, D3.A, R23.1, R24.1, R29.1, R30.2, TP24.TP, TP25.TP, TP26.TP, U10.6 (SGND), U10.19 (VPRG2), U10.35 (PGND), U10.36 (PGND), U10.37 (PGND); also elsewhere on the board
IMON: U10.17 (IMON)
INTVCC: C9.1, R18.1, R19.2, R25.1, R28.1, U10.21 (INTVCC)
unnamed: C4.2, U10.27 (BOOST)
unnamed: C36.1, C47.1, L1.2, L5.1, U10.10 (VFB), U10.20 (EXTVCC)
unnamed: C4.1, L1.1, U10.24 (SW), U10.25 (SW), U10.26 (SW)
unnamed: C39.1, C42.1, L6.2, L7.1
unnamed: R17.1, U10.3 (RUN)
unnamed: R23.2, U10.11 (FREQ)
unnamed: R28.2, R29.2, U10.12 (PLLIN/MODE)
unnamed: R25.2, U10.9 (ITH)
unnamed: C31.1, C37.1, C40.1, C41.1, C43.+, C46.1, L7.2, R17.2, U10.30 (VIN), U10.31 (VIN), U10.32 (VIN)
PGOOD: R18.2, U10.14 (PGOOD)
RIND: R24.2, U10.8 (RIND)
SS: C35.1, R19.1, U10.15 (SS)
VIN: C50.1, D5.A, TP23.TP, TP45.TP; also elsewhere on the board
VIN1: C38.1, D3.C, D5.C, L6.1, R30.1
VIN_SOM: C8.1, C30.1, C32.1, L5.2, TP10.TP; also elsewhere on the board

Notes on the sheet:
VPRG1=FLOAT VPRG2=SGND SETS VOUT=5V
FREQUENCY =(17.8-7.5)x40 =412KHz
RIND=1/(7.5xPWR Inductor)
Polulate one or the other
SKIP
BURST
15uH
TVS SMA 100V
POWER
C35 is for Adjast soft start time period

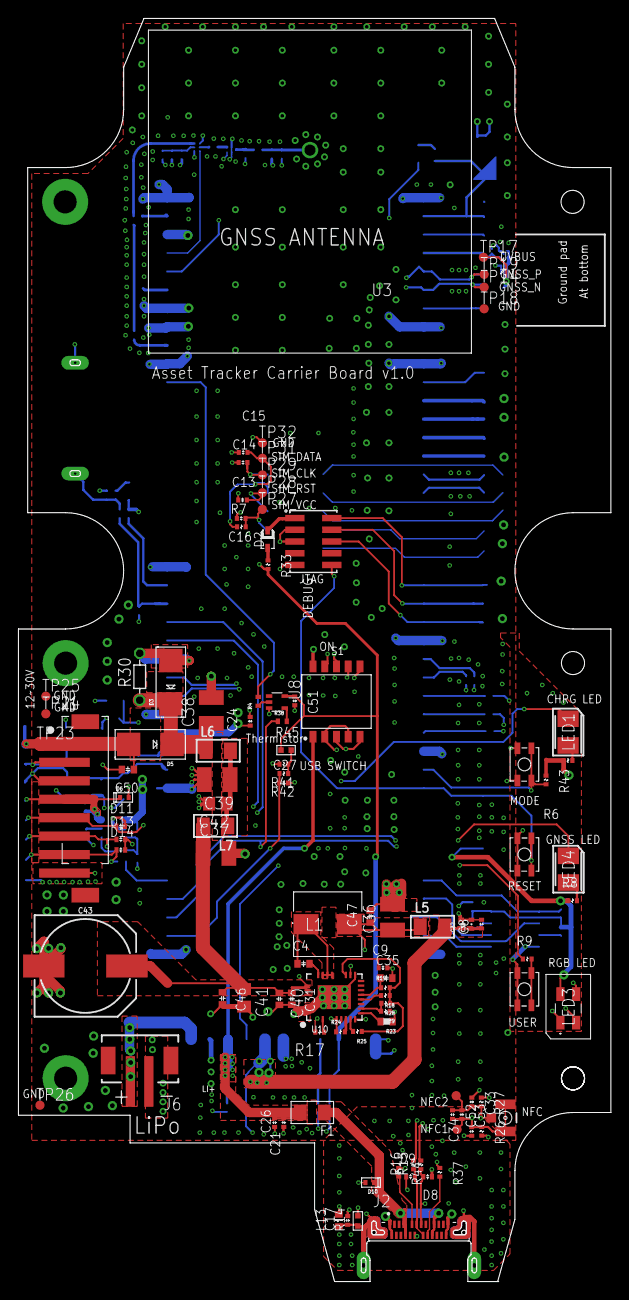
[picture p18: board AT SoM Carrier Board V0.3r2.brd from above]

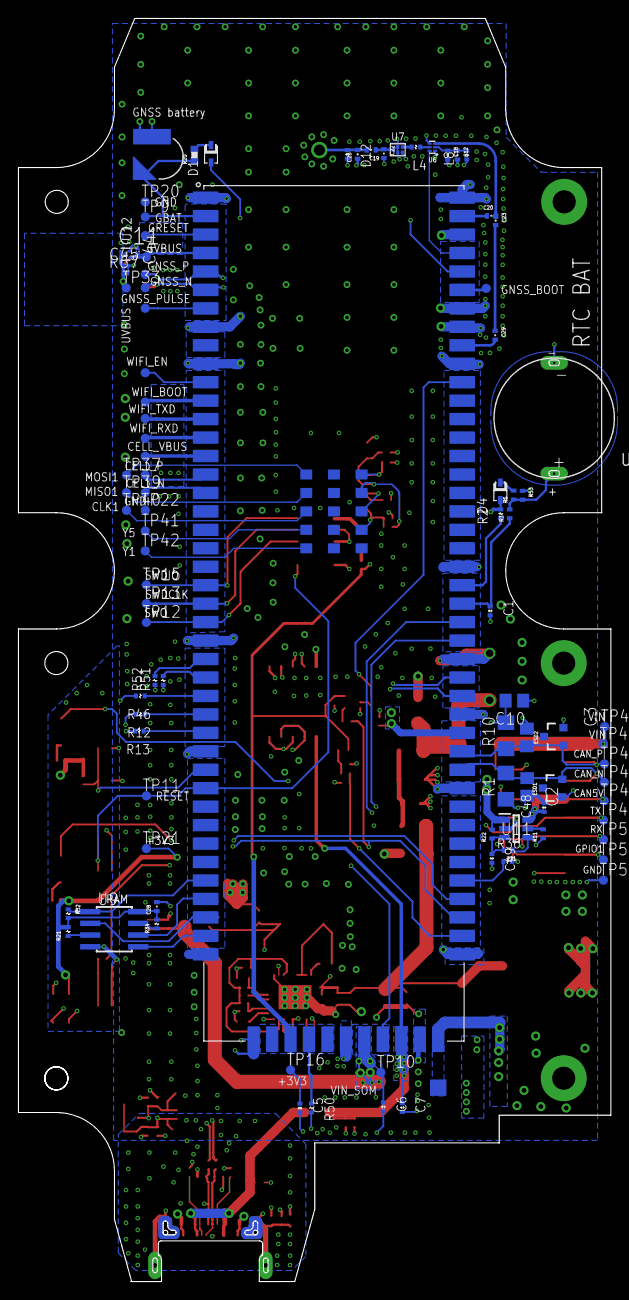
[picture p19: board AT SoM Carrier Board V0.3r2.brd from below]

Board: 4 copper layers, 64.2 x 136.9 mm, 200 parts (94 on the bottom side), 117 nets.

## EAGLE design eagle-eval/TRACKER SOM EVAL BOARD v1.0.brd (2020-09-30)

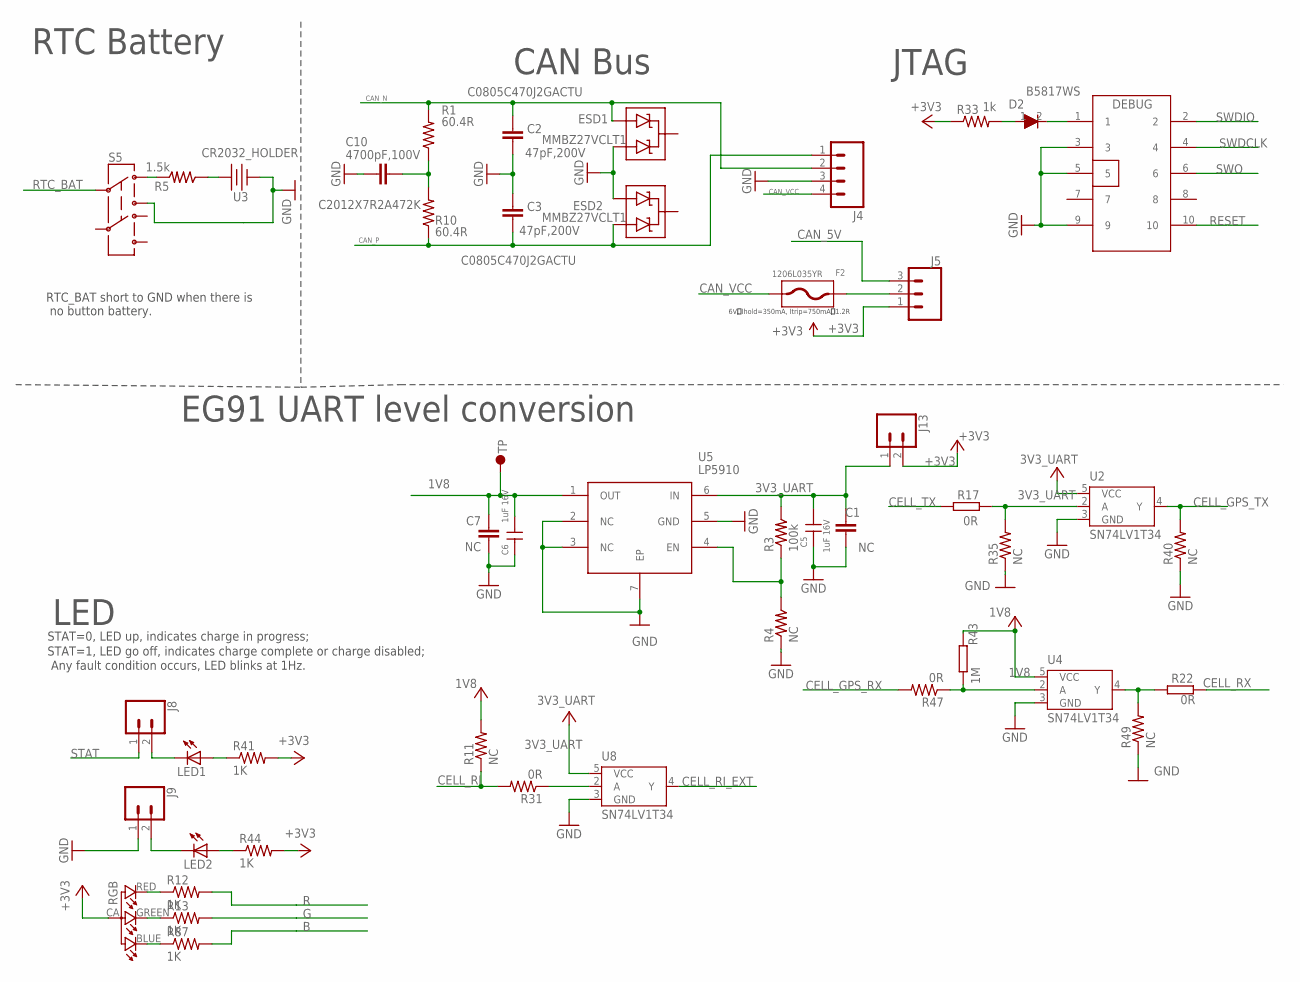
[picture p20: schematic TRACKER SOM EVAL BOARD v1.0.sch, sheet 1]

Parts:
C1, C7: NC; C0805
C2, C3: 47pF,200V; C0805; PART_NUMBER C0805C470J2GACTU
C5, C6: 1uF 16V; C0603
C10: 4700pF,100V; C0805; PART_NUMBER C2012X7R2A472K
D2: B5817WS; SOD-323
DEBUG: CON 2X5P; CON5X2_1.27
ESD1, ESD2: MMBZ27VCLT1; SOT23-3
F2: 1206L035YR; R1206
J4: M04SCREW; SCREWTERMINAL-3.5MM-4; PARTNO OSTTE040104
J5: CONN_03_2.54MM; 1X03
J8, J9, J13: CONN_02; 1X02
LED1, LED2: LED0603; LED-0603
R1, R10: 60.4R; R1206
R3: 100k; R-0402S
R4: NC; R-0402S
R5: 1.5k; R-0402S
R11, R35, R40, R49: NC; R0402_B
R12, R13, R41, R44, R87: 1K; R0603
R17, R22: 0R; R0603
R31, R47: 0R; R0402_B
R33: 1k; 0603
R43: 1M; REDBEAR_R0603
RGB: RGB-LED-CLMVB-FKARGB; PLCC4-2MM-RGB
S5: SWITCH-DPDT; SWITCH-2.5X3.2-6
U2, U4, U8: SN74LV1T34; SC70-5
U3: CR2032_HOLDER
U5: LP5910; QFN6P
U$4: TP5; TP30_TOP

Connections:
1V8: C6.1, C7.1, R11.2, R43.1, U4.5 (VCC), U5.1 (OUT), U$4.P$1
3V3_UART: C1.1, C5.1, J13.1, R3.2, U2.5 (VCC), U5.6 (IN), U8.5 (VCC)
+3V3: J5.1, J13.2, R33.1, R41.2, R44.2, RGB.CA (1); also elsewhere on the board
B: R87.2; also elsewhere on the board
CAN_5V: J5.3; also elsewhere on the board
CAN_N: C2.1, ESD1.2 (A2), J4.2, R1.2; also elsewhere on the board
CAN_P: C3.2, ESD2.1 (A1), J4.1, R10.1; also elsewhere on the board
CAN_VCC: F2.1, J4.4
CELL_GPS_RX: R47.2; also elsewhere on the board
CELL_GPS_TX: R40.2, U2.4 (Y); also elsewhere on the board
CELL_RI: R11.1, R31.2; also elsewhere on the board
CELL_RI_EXT: U8.4 (Y); also elsewhere on the board
CELL_RX: R22.1; also elsewhere on the board
CELL_TX: R17.2; also elsewhere on the board
G: R13.2; also elsewhere on the board
GND: C1.2, C2.2, C3.1, C5.2, C6.2, C7.2, C10.1, DEBUG.3, DEBUG.5, DEBUG.9, ESD1.1 (A1), ESD2.2 (A2), J4.3, J9.1, R4.1, R35.1, R40.1, R49.1, S5.3, U2.3 (GND), U3.-, U4.3 (GND), U5.2 (NC), U5.3 (NC), U5.5 (GND), U5.7 (EP), U8.3 (GND); also elsewhere on the board
unnamed: LED1.A, R41.1
unnamed: J8.2, LED1.C
unnamed: LED2.A, R44.1
unnamed: J9.2, LED2.C
unnamed: C10.2, R1.1, R10.2
unnamed: R17.1, R35.2, U2.2 (A)
unnamed: R31.1, U8.2 (A)
unnamed: R3.1, R4.2, U5.4 (EN)
unnamed: R5.2, S5.1
unnamed: R12.1, RGB.RED (4)
unnamed: R43.2, R47.1, U4.2 (A)
unnamed: F2.2, J5.2
unnamed: R22.2, R49.2, U4.4 (Y)
unnamed: R87.1, RGB.BLUE (2)
unnamed: R13.1, RGB.GREEN (3)
unnamed: R5.1, U3.+
unnamed: D2.1, R33.2
unnamed: D2.2, DEBUG.1
R: R12.2; also elsewhere on the board
RESET: DEBUG.10; also elsewhere on the board
RTC_BAT: S5.2; also elsewhere on the board
STAT: J8.1; also elsewhere on the board
SWDCLK: DEBUG.4; also elsewhere on the board
SWDIO: DEBUG.2; also elsewhere on the board
SWO: DEBUG.6; also elsewhere on the board

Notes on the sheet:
CAN Bus
EG91 UART level conversion
LED
JTAG
RTC Battery
RTC_BAT short to GND when there is no button battery.
STAT=0, LED up, indicates charge in progress;
STAT=1, LED go off, indicates charge complete or charge disabled;
Any fault condition occurs, LED blinks at 1Hz.
6V，Ihold=350mA, Itrip=750mA，1.2R

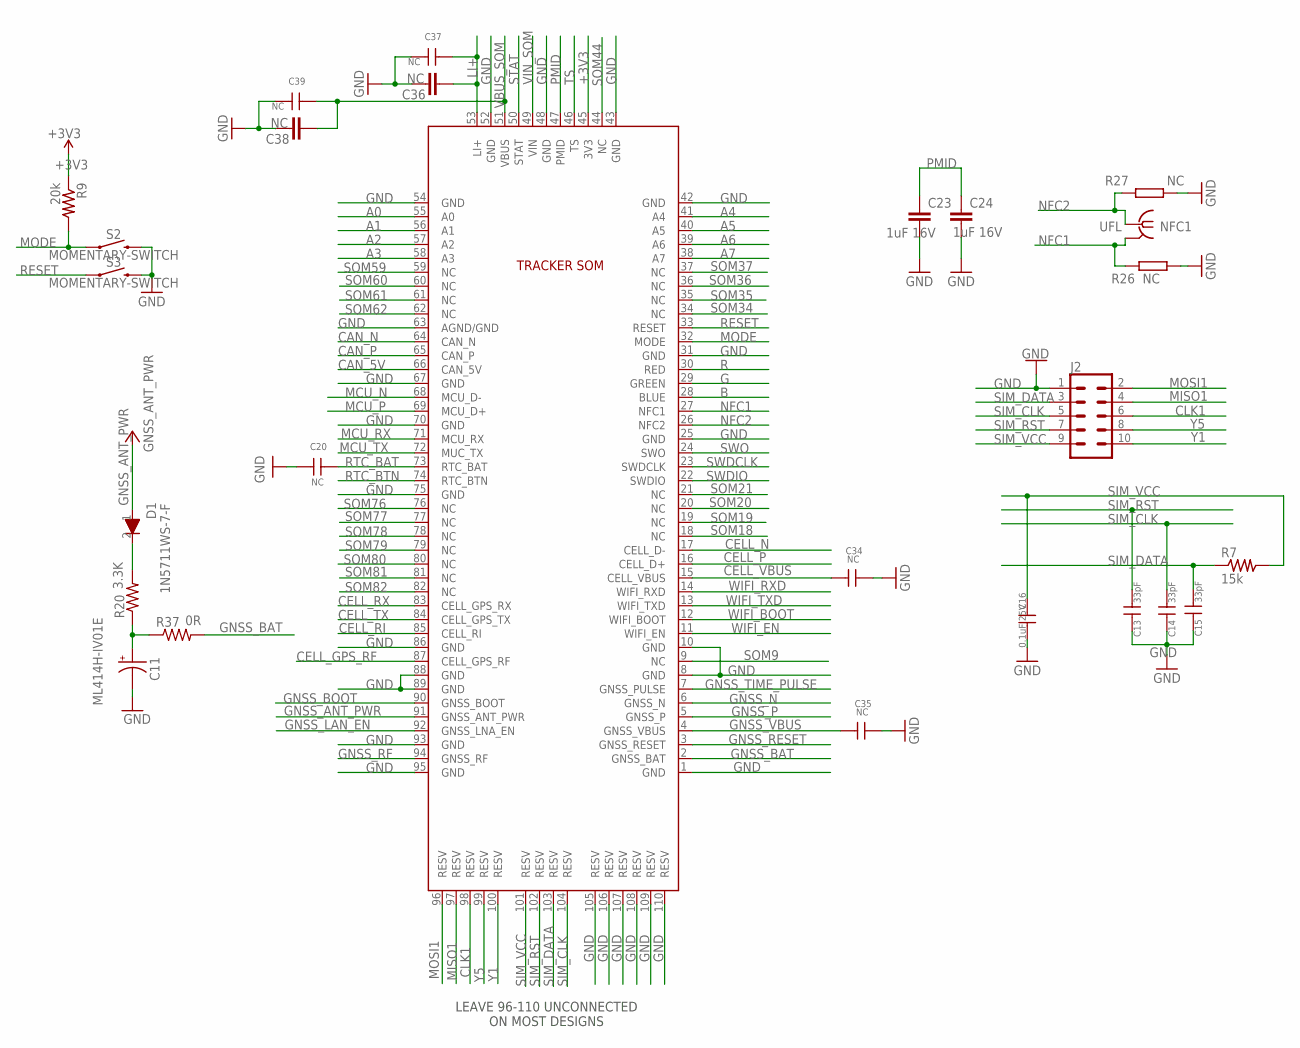
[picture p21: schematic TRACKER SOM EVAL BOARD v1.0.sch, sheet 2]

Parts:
C11: ML414H-IV01E; ML414H
C13, C14, C15: 33pF; C-0402
C16: 0.1uF 25V; C-0402
C20, C34, C35, C37, C39: NC; C-0402
C23, C24: 1uF 16V; C0805
C36, C38: NC; C1206
D1: 1N5711WS-7-F; SOD-323
J2: CONN_05X2PTH; 2X5
NFC1: UFL; IPEX-20279-001E
R7: 15k; R-0402S
R9: 20k; R-0402S
R20: 3.3K; 0603
R26, R27: NC; R-0402S
R37: 0R; 0603
S2, S3: MOMENTARY-SWITCH; TACTILE_SWITCH_PTH_6.0MM
U1: TRACKER-SOM-3A

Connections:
+3V3: R9.1, U1.45 (3V3); also elsewhere on the board
A0: U1.55 (A0); also elsewhere on the board
A1: U1.56 (A1); also elsewhere on the board
A2: U1.57 (A2); also elsewhere on the board
A3: U1.58 (A3); also elsewhere on the board
A4: U1.41 (A4); also elsewhere on the board
A5: U1.40 (A5); also elsewhere on the board
A6: U1.39 (A6); also elsewhere on the board
A7: U1.38 (A7); also elsewhere on the board
B: U1.28 (BLUE); also elsewhere on the board
CAN_5V: U1.66 (CAN_5V); also elsewhere on the board
CAN_N: U1.64 (CAN_N); also elsewhere on the board
CAN_P: U1.65 (CAN_P); also elsewhere on the board
CELL_GPS_RF: U1.87 (CELL_GPS_RF)
CELL_N: U1.17 (CELL_D-); also elsewhere on the board
CELL_P: U1.16 (CELL_D+); also elsewhere on the board
CELL_RI: U1.85 (CELL_RI); also elsewhere on the board
CELL_RX: U1.83 (CELL_GPS_RX); also elsewhere on the board
CELL_TX: U1.84 (CELL_GPS_TX); also elsewhere on the board
CELL_VBUS: C34.2, U1.15 (CELL_VBUS); also elsewhere on the board
CLK1: J2.6, U1.98 (RESV)
G: U1.29 (GREEN); also elsewhere on the board
GND: C11.-, C13.1, C14.1, C15.1, C16.2, C20.1, C23.2, C24.2, C34.1, C35.1, C36.1, C37.1, C38.1, C39.1, J2.1, R26.2, R27.1, S2.3 (2), S3.3 (2), U1.1 (GND), U1.8 (GND), U1.10 (GND), U1.25 (GND), U1.31 (GND), U1.42 (GND), U1.43 (GND), U1.48 (GND), U1.52 (GND), U1.54 (GND), U1.63 (AGND/GND), U1.67 (GND), U1.70 (GND), U1.75 (GND), U1.86 (GND), U1.88 (GND), U1.89 (GND), U1.93 (GND), U1.95 (GND), U1.105 (RESV), U1.106 (RESV), U1.107 (RESV), U1.108 (RESV), U1.109 (RESV), U1.110 (RESV); also elsewhere on the board
GNSS_ANT_PWR: D1.1, U1.91 (GNSS_ANT_PWR)
GNSS_BAT: R37.2, U1.2 (GNSS_BAT)
GNSS_BOOT: U1.90 (GNSS_BOOT)
GNSS_LAN_EN: U1.92 (GNSS_LNA_EN)
GNSS_N: U1.6 (GNSS_N); also elsewhere on the board
GNSS_P: U1.5 (GNSS_P); also elsewhere on the board
GNSS_RESET: U1.3 (GNSS_RESET)
GNSS_RF: U1.94 (GNSS_RF)
GNSS_TIME_PULSE: U1.7 (GNSS_PULSE); also elsewhere on the board
GNSS_VBUS: C35.2, U1.4 (GNSS_VBUS); also elsewhere on the board
LI+: C36.2, C37.2, U1.53 (LI+); also elsewhere on the board
MCU_N: U1.68 (MCU_D-); also elsewhere on the board
MCU_P: U1.69 (MCU_D+); also elsewhere on the board
MCU_RX: U1.71 (MCU_RX); also elsewhere on the board
MCU_TX: U1.72 (MUC_TX); also elsewhere on the board
MISO1: J2.4, U1.97 (RESV)
MODE: R9.2, S2.1, U1.32 (MODE); also elsewhere on the board
MOSI1: J2.2, U1.96 (RESV)
unnamed: D1.2, R20.2
unnamed: C11.+, R20.1, R37.1
NFC1: NFC1.2@1 (GND), NFC1.2@2 (GND), R26.1, U1.27 (NFC1); also elsewhere on the board
NFC2: NFC1.1, R27.2, U1.26 (NFC2); also elsewhere on the board
PMID: C23.1, C24.1, U1.47 (PMID); also elsewhere on the board
R: U1.30 (RED); also elsewhere on the board
RESET: S3.1, U1.33 (RESET); also elsewhere on the board
RTC_BAT: C20.2, U1.73 (RTC_BAT); also elsewhere on the board
RTC_BTN: U1.74 (RTC_BTN); also elsewhere on the board
SIM_CLK: C14.2, J2.5, U1.104 (RESV)
SIM_DATA: C15.2, J2.3, R7.1, U1.103 (RESV)
SIM_RST: C13.2, J2.7, U1.102 (RESV)
SIM_VCC: C16.1, J2.9, R7.2, U1.101 (RESV)
SOM9: U1.9 (NC); also elsewhere on the board
SOM18: U1.18 (NC); also elsewhere on the board
SOM19: U1.19 (NC); also elsewhere on the board
SOM20: U1.20 (NC); also elsewhere on the board
SOM21: U1.21 (NC); also elsewhere on the board
SOM34: U1.34 (NC); also elsewhere on the board
SOM35: U1.35 (NC); also elsewhere on the board
SOM36: U1.36 (NC); also elsewhere on the board
SOM37: U1.37 (NC); also elsewhere on the board
SOM44: U1.44 (NC); also elsewhere on the board
SOM59: U1.59 (NC); also elsewhere on the board
SOM60: U1.60 (NC); also elsewhere on the board
SOM61: U1.61 (NC); also elsewhere on the board
SOM62: U1.62 (NC); also elsewhere on the board
SOM76: U1.76 (NC); also elsewhere on the board
SOM77: U1.77 (NC); also elsewhere on the board
SOM78: U1.78 (NC); also elsewhere on the board
SOM79: U1.79 (NC); also elsewhere on the board
SOM80: U1.80 (NC); also elsewhere on the board
SOM81: U1.81 (NC); also elsewhere on the board
SOM82: U1.82 (NC); also elsewhere on the board
STAT: U1.50 (STAT); also elsewhere on the board
SWDCLK: U1.23 (SWDCLK); also elsewhere on the board
SWDIO: U1.22 (SWDIO); also elsewhere on the board
SWO: U1.24 (SWO); also elsewhere on the board
TS: U1.46 (TS); also elsewhere on the board
VBUS_SOM: C38.2, C39.2, U1.51 (VBUS); also elsewhere on the board
VIN_SOM: U1.49 (VIN); also elsewhere on the board
WIFI_BOOT: U1.12 (WIFI_BOOT); also elsewhere on the board
WIFI_EN: U1.11 (WIFI_EN); also elsewhere on the board
WIFI_RXD: U1.14 (WIFI_RXD); also elsewhere on the board
WIFI_TXD: U1.13 (WIFI_TXD); also elsewhere on the board
Y1: J2.10, U1.100 (RESV)
Y5: J2.8, U1.99 (RESV)

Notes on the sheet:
LEAVE 96-110 UNCONNECTED ON MOST DESIGNS

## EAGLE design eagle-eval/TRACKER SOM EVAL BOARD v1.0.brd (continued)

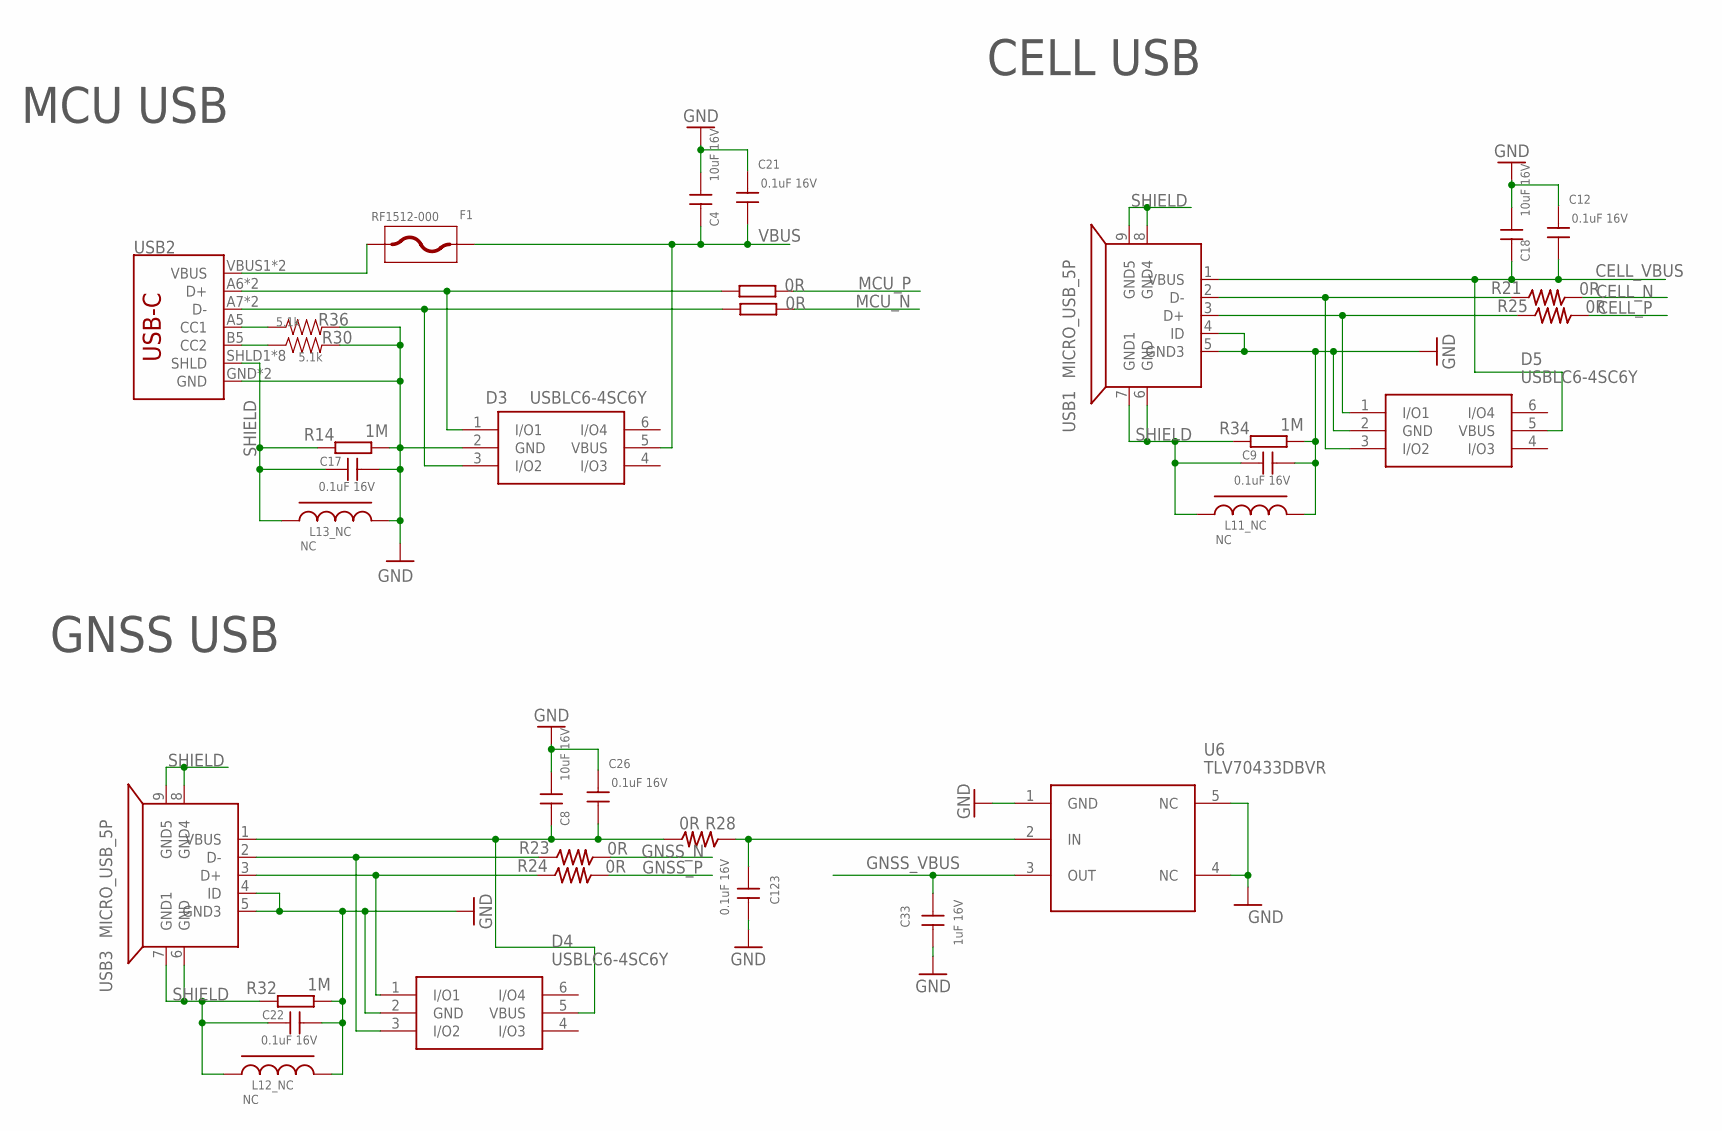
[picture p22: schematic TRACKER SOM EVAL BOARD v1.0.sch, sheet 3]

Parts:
C4, C8, C18: 10uF 16V; REDBEAR_C0603
C9, C17, C22: 0.1uF 16V; PARTICLE-SZ_C-0402
C12, C21, C26, C123: 0.1uF 16V; C-0402
C33: 1uF 16V; C0603
D3, D4, D5: USBLC6-4SC6Y; SOT95P280X145-6N
F1: RF1512-000; R1206
L11_NC, L12_NC, L13_NC: NC; R-0603A
R14, R32, R34: 1M; REDBEAR_R0603
R15, R16, R21, R23, R24, R25, R28: 0R; R-0402S
R30, R36: 5.1k; C0402
U6: TLV70433DBVR
USB1, USB3: MICRO_USB_5P; MICRO_USB
USB2: USB_C16PIN; USB-C-16P

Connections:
CELL_N: R21.2; also elsewhere on the board
CELL_P: R25.2; also elsewhere on the board
CELL_VBUS: C12.1, C18.2, D5.5 (VBUS), USB1.1 (VBUS); also elsewhere on the board
GND: C4.1, C8.1, C9.2, C12.2, C17.2, C18.1, C21.2, C22.2, C26.2, C33.2, C123.2, D3.2 (GND), D4.2 (GND), D5.2 (GND), L11_NC.2, L12_NC.2, L13_NC.2, R14.2, R30.2, R32.2, R34.2, R36.2, U6.1 (GND), U6.4 (NC), U6.5 (NC), USB1.4 (ID), USB1.5 (GND3), USB2.GND, USB2.GND2 (GND), USB3.4 (ID), USB3.5 (GND3); also elsewhere on the board
GNSS_N: R23.2; also elsewhere on the board
GNSS_P: R24.2; also elsewhere on the board
GNSS_VBUS: C33.1, U6.3 (OUT); also elsewhere on the board
MCU_N: R15.2; also elsewhere on the board
MCU_P: R16.2; also elsewhere on the board
unnamed: D3.3 (I/O2), R15.1, USB2.A7 (D-), USB2.B7 (D-)
unnamed: D3.1 (I/O1), R16.1, USB2.A6 (D+), USB2.B6 (D+)
unnamed: D4.3 (I/O2), R23.1, USB3.2 (D-)
unnamed: D5.3 (I/O2), R21.1, USB1.2 (D-)
unnamed: D5.1 (I/O1), R25.1, USB1.3 (D+)
unnamed: F1.1, USB2.VBUS1 (VBUS), USB2.VBUS2 (VBUS)
unnamed: D4.1 (I/O1), R24.1, USB3.3 (D+)
unnamed: C123.1, R28.1, U6.2 (IN)
unnamed: R30.1, USB2.B5 (CC2)
unnamed: R36.1, USB2.A5 (CC1)
SHIELD: C9.1, C17.1, C22.1, L11_NC.1, L12_NC.1, L13_NC.1, R14.1, R32.1, R34.1, USB1.6 (GND), USB1.7 (GND1), USB1.8 (GND4), USB1.9 (GND5), USB2.SHLD1 (SHLD), USB2.SHLD2 (SHLD), USB2.SHLD3 (SHLD), USB2.SHLD4 (SHLD), USB2.SHLD5 (SHLD), USB2.SHLD6 (SHLD), USB2.SHLD7 (SHLD), USB2.SHLD8 (SHLD), USB3.6 (GND), USB3.7 (GND1), USB3.8 (GND4), USB3.9 (GND5)
U_VBUS: C8.2, C26.1, D4.5 (VBUS), R28.2, USB3.1 (VBUS)
VBUS: C4.2, C21.1, D3.5 (VBUS), F1.2; also elsewhere on the board

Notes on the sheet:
MCU USB
CELL USB
GNSS USB

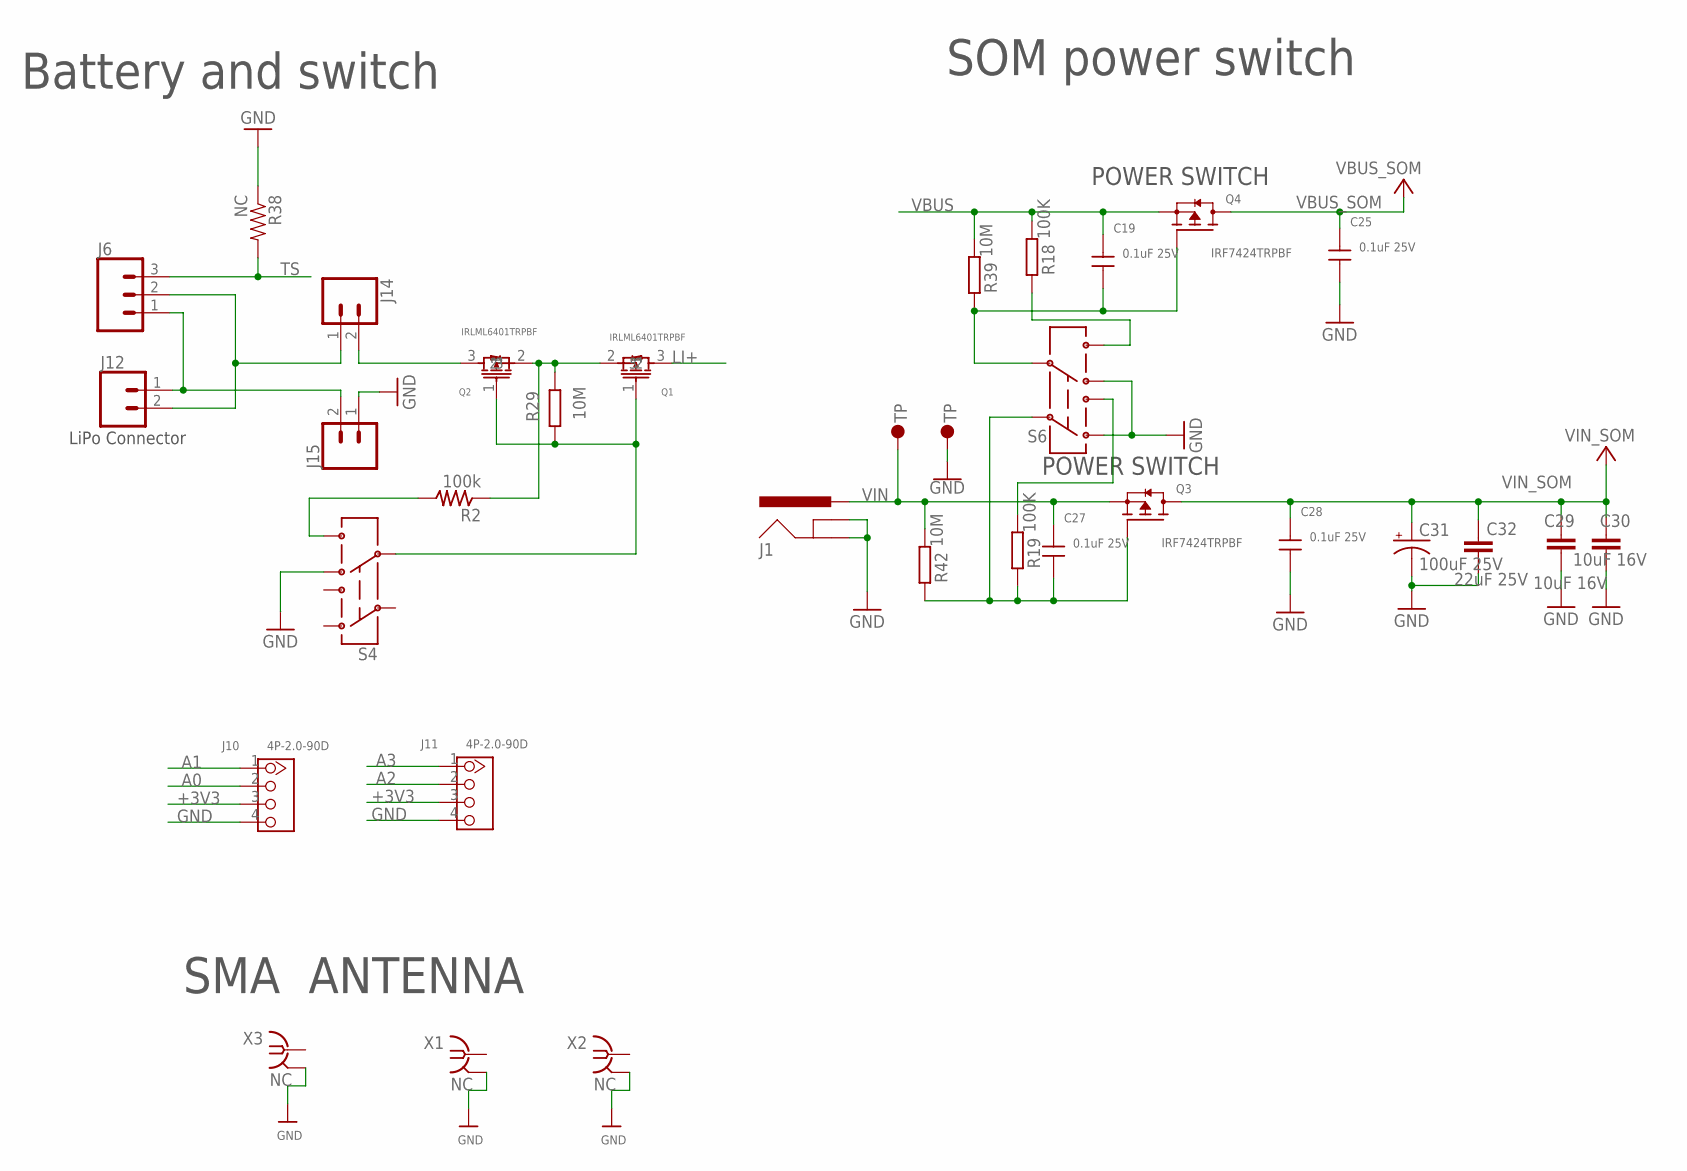
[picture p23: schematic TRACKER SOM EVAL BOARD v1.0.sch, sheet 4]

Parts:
C19, C25, C27, C28: 0.1uF 25V; C-0402
C29, C30: 10uF 16V; C0805
C31: 100uF 25V; PANASONIC_D
C32: 22uF 25V; C1206
J1: POWER_JACKSLT; POWER_JACK_SLOT
J6: CONN_03_2.54MM; 1X03
J10, J11: 4P-2.0-90D; HW4-2.0-90D
J12: CONN_02-JST-2MM-SMT; JST-2-SMD
J14, J15: CONN_02; 1X02
Q1, Q2: IRLML6401TRPBF; SOT-23
Q3, Q4: IRF7424TRPBF; PMOS_IRF7424
R2: 100k; R-0402S
R18, R19: 100K; R0603
R29, R39, R42: 10M; R0603
R38: NC; 0603-RES
S4, S6: SWITCH-DPDT; SWITCH-2.5X3.2-6
U$9, U$10: TP2; TP70_BOT
X1, X2, X3: NC; BU-SMA-G

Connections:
+3V3: J10.3, J11.3; also elsewhere on the board
A0: J10.2; also elsewhere on the board
A1: J10.1; also elsewhere on the board
A2: J11.2; also elsewhere on the board
A3: J11.1; also elsewhere on the board
GND: C25.1, C28.1, C29.2, C30.2, C31.-, C32.2, J1.GND@1 (GNDBREAK), J1.GND@2 (GND), J10.4, J11.4, J15.1, R38.1, S4.4, S6.1, S6.4, U$10.P$1, X1.2, X1.3 (2), X1.4 (2), X1.5 (2), X2.2, X2.3 (2), X2.4 (2), X2.5 (2), X3.2, X3.3 (2), X3.4 (2), X3.5 (2); also elsewhere on the board
LI+: Q1.3; also elsewhere on the board
unnamed: J14.2, Q2.3
unnamed: R2.2, S4.6
unnamed: J6.1, J12.1 (2), J15.2
unnamed: R18.1, S6.6
unnamed: R19.2, S6.3
unnamed: J6.2, J12.2 (1), J14.1
unnamed: Q1.2, Q2.2, R2.1, R29.2
unnamed: Q1.1, Q2.1, R29.1, S4.5
SYS_PWR_EN1: C19.1, Q4.4 (G), R39.1, S6.5
SYS_PWR_EN2: C27.1, Q3.4 (G), R19.1, R42.1, S6.2
TS: J6.3, R38.2; also elsewhere on the board
VBUS: C19.2, Q4.1 (S), Q4.2 (S), Q4.3 (S), R18.2, R39.2; also elsewhere on the board
VBUS_SOM: C25.2, Q4.5 (D), Q4.6 (D), Q4.7 (D), Q4.8 (D); also elsewhere on the board
VIN: C27.2, J1.PWR, Q3.1 (S), Q3.2 (S), Q3.3 (S), R42.2, U$9.P$1
VIN_SOM: C28.2, C29.1, C30.1, C31.+, C32.1, Q3.5 (D), Q3.6 (D), Q3.7 (D), Q3.8 (D); also elsewhere on the board

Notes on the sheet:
LiPo Connector
SMA ANTENNA
SOM power switch
Battery and switch
POWER SWITCH

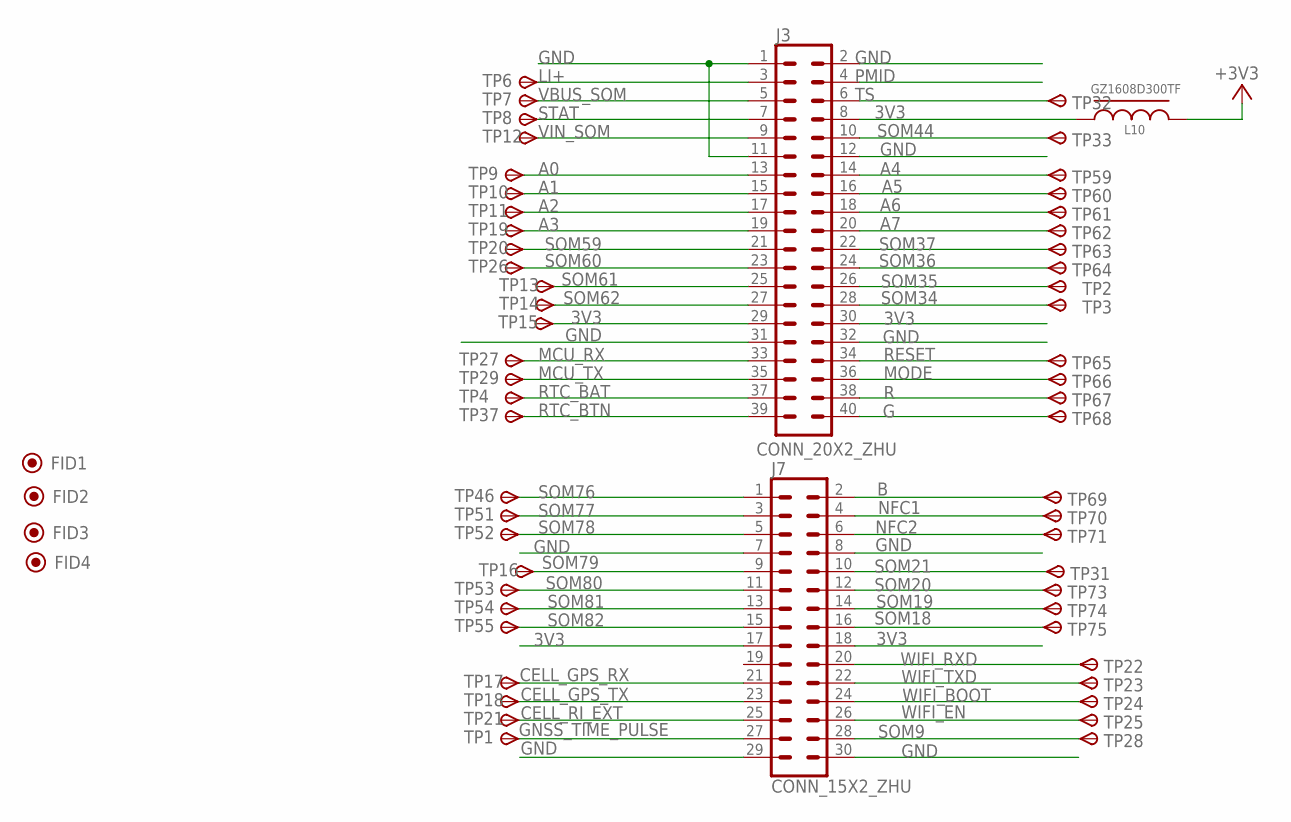
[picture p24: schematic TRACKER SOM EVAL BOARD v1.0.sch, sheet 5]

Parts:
FID1, FID2, FID3, FID4: FIDUCIAL_2; FID_TOP_1MM
J3: CONN_20X2_ZHU; SMD_2*20
J7: CONN_15X2_ZHU; SMD_2*15
L10: GZ1608D300TF; R-0603A
TP1, TP2, TP3, TP4, TP6, TP7, TP8, TP9, TP10, TP11, TP12, TP13, TP14, TP15, TP16, TP17, TP18, TP19, TP20, TP21, TP22, TP23, TP24, TP25, TP26, TP27, TP28, TP29, TP31, TP32, TP33, TP37, TP46, TP51, TP52, TP53, TP54, TP55, TP59, TP60, TP61, TP62, TP63, TP64, TP65, TP66, TP67, TP68, TP69, TP70, TP71, TP73, TP74, TP75: TPSB1,27; B1,27

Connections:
3V3: J3.8, J3.29, J3.30, J7.17, J7.18, L10.1, TP15.TP
+3V3: L10.2; also elsewhere on the board
A0: J3.13, TP9.TP; also elsewhere on the board
A1: J3.15, TP10.TP; also elsewhere on the board
A2: J3.17, TP11.TP; also elsewhere on the board
A3: J3.19, TP19.TP; also elsewhere on the board
A4: J3.14, TP59.TP; also elsewhere on the board
A5: J3.16, TP60.TP; also elsewhere on the board
A6: J3.18, TP61.TP; also elsewhere on the board
A7: J3.20, TP62.TP; also elsewhere on the board
B: J7.2, TP69.TP; also elsewhere on the board
CELL_GPS_RX: J7.21, TP17.TP; also elsewhere on the board
CELL_GPS_TX: J7.23, TP18.TP; also elsewhere on the board
CELL_RI_EXT: J7.25, TP21.TP; also elsewhere on the board
G: J3.40, TP68.TP; also elsewhere on the board
GND: J3.1, J3.2, J3.11, J3.12, J3.31, J3.32, J7.7, J7.8, J7.29, J7.30; also elsewhere on the board
GNSS_TIME_PULSE: J7.27, TP1.TP; also elsewhere on the board
LI+: J3.3, TP6.TP; also elsewhere on the board
MCU_RX: J3.33, TP27.TP; also elsewhere on the board
MCU_TX: J3.35, TP29.TP; also elsewhere on the board
MODE: J3.36, TP66.TP; also elsewhere on the board
NFC1: J7.4, TP70.TP; also elsewhere on the board
NFC2: J7.6, TP71.TP; also elsewhere on the board
PMID: J3.4; also elsewhere on the board
R: J3.38, TP67.TP; also elsewhere on the board
RESET: J3.34, TP65.TP; also elsewhere on the board
RTC_BAT: J3.37, TP4.TP; also elsewhere on the board
RTC_BTN: J3.39, TP37.TP; also elsewhere on the board
SOM9: J7.28, TP28.TP; also elsewhere on the board
SOM18: J7.16, TP75.TP; also elsewhere on the board
SOM19: J7.14, TP74.TP; also elsewhere on the board
SOM20: J7.12, TP73.TP; also elsewhere on the board
SOM21: J7.10, TP31.TP; also elsewhere on the board
SOM34: J3.28, TP3.TP; also elsewhere on the board
SOM35: J3.26, TP2.TP; also elsewhere on the board
SOM36: J3.24, TP64.TP; also elsewhere on the board
SOM37: J3.22, TP63.TP; also elsewhere on the board
SOM44: J3.10, TP33.TP; also elsewhere on the board
SOM59: J3.21, TP20.TP; also elsewhere on the board
SOM60: J3.23, TP26.TP; also elsewhere on the board
SOM61: J3.25, TP13.TP; also elsewhere on the board
SOM62: J3.27, TP14.TP; also elsewhere on the board
SOM76: J7.1, TP46.TP; also elsewhere on the board
SOM77: J7.3, TP51.TP; also elsewhere on the board
SOM78: J7.5, TP52.TP; also elsewhere on the board
SOM79: J7.9, TP16.TP; also elsewhere on the board
SOM80: J7.11, TP53.TP; also elsewhere on the board
SOM81: J7.13, TP54.TP; also elsewhere on the board
SOM82: J7.15, TP55.TP; also elsewhere on the board
STAT: J3.7, TP8.TP; also elsewhere on the board
TS: J3.6, TP32.TP; also elsewhere on the board
VBUS_SOM: J3.5, TP7.TP; also elsewhere on the board
VIN_SOM: J3.9, TP12.TP; also elsewhere on the board
WIFI_BOOT: J7.24, TP24.TP; also elsewhere on the board
WIFI_EN: J7.26, TP25.TP; also elsewhere on the board
WIFI_RXD: J7.20, TP22.TP; also elsewhere on the board
WIFI_TXD: J7.22, TP23.TP; also elsewhere on the board

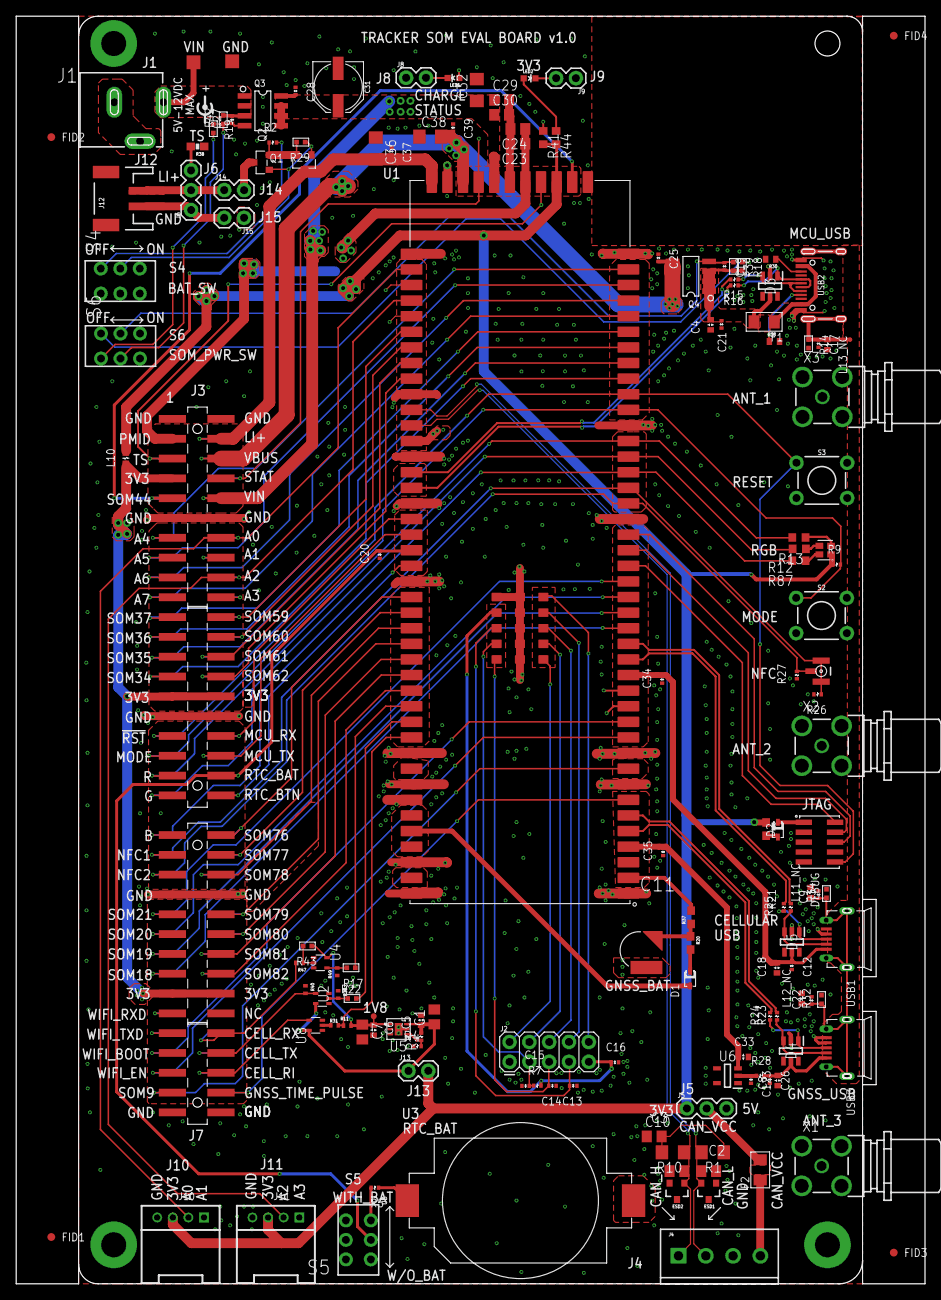
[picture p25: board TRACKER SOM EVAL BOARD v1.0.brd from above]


Board: 4 copper layers, 116.5 x 162.5 mm, 201 parts (56 on the bottom side), 132 nets.

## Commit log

2020-09-30 Add pdf schematics
2021-02-17 Update carrier board
    [AT SoM Carrier Board V0.3r2.brd, AT SoM Carrier Board V0.3r2.sch, AT SoM Carrier Board V1.1.brd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]

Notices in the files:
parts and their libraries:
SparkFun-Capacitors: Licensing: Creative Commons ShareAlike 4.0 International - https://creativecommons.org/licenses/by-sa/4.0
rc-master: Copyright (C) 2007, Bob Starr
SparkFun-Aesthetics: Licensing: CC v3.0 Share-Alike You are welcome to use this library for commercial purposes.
